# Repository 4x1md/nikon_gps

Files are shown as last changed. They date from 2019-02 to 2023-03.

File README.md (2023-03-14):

# DIY GPS Module for Nikon DSLR

The Nikon GPS project is a compact and lightweight DIY module which adds GPS functionality to Nikon DSLR cameras. It adds the ability to record location data for each photo in the EXIF and later view it on a map.

The module is attached to the flash hot shoe mount and connects to the camera's dedicated GPS port. The GPS gets its power from the camera and transmits the received GPS NMEA sentences using UART at 4800 bps. It also features an on/off button and a LED indicator which shows when the GPS module is active.

The project was created mostly to advance my DIY and electronics skills.

## Overview

The idea of building a GPS for my Nikon DSLR me after building the [GPS module for my Yaesu VX-8DE transceiver](https://github.com/4x1md/vx8_gps). I searched the internet and found some projects, some of which had a very small size. For my project I chose RG1411 GPS module which is only 10x10mm in size. It requires 3.3V which can be supplied by the camera.

The first version of the GPS had a linear voltage regulator powering the GPS module. This solution had one big disadvantage: the GPS module was turned off completely and didn't keep any GPS data while it was off. Each time the module was turned on it had to acquire all the required GPS data again and consumed more current during the first minutes after power on. The delay of 3-5 minutes and even more made this GPS module impractical while walking in a city when I turned it on and off very often in order to save camera's battery.

The second version of this GPS project had the following changes:

1. The linear voltage regulator was replaced with a switching power supply with a very high efficiency at low currents.

2. On/off button puts the GPS module is a sleep mode instead of turning it off. In this mode it keeps the GPS data all the time when the GPS is connected to the camera and its start time is much shorter than during a full power-on cycle.

This document describes the latest version of this project. The first version of this project (revision A) is presented in [revision-a.md](docs/revision-a.md).

## Circuit Diagram

The project has the following circuits: GPS module, power supply, on/off switch, logic level shifter and LEDs. All the circuits are assembled on the same PCB.

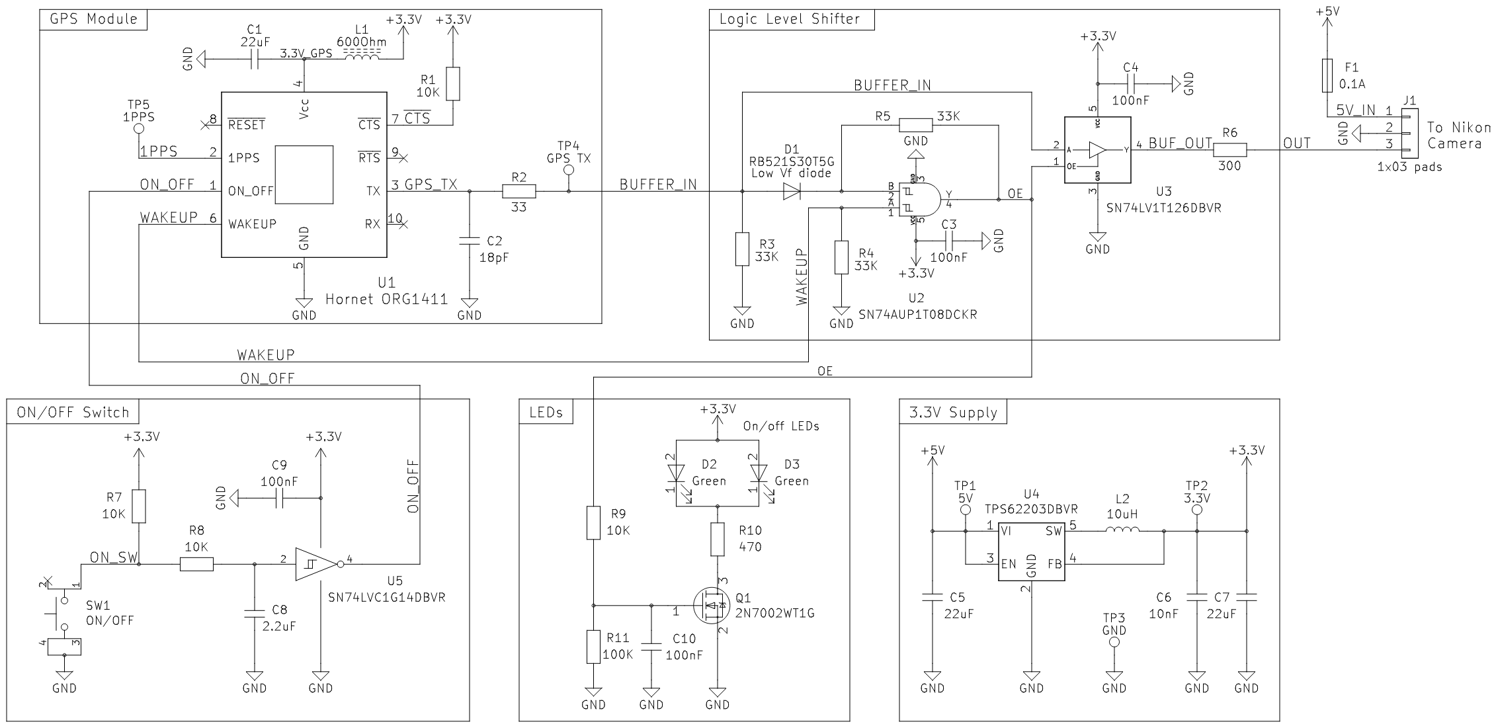
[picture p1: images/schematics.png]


1. **GPS module.** Hornet ORG1411 was chosen due to its small footprint and good performance. It is powered from the 3.3V supply and is connected in UART mode.

2. **Power supply.** TI TPS62203DBVR is a switching voltage regulator with fixed 3.3V output. It requires only an inductor and filter capacitors in order to work. It features more than 90% at the currents below 1mA. Such efficiency is important for reducing power consumption from the camera.

3. **On/off button.** The button is used to toggle the ON_OFF pin of the GPS for putting it into sleep mode or waking it up. The button is debounced by an RC-filter with a Schmitt trigger.

4. **Logic level shifter.** The logic level shifting circuit converts the 1.8V logic levels of the GPS to 3.3V levels required by the camera. When the GPS is in the sleep mode the level shifter enters high-Z mode. The enable pin of U3 is controlled by a circuit which acts like a flip-flop. If the WAKEUP pin of the GPS is LOW, the output of the AND gate U2 is also LOW and the output of U3 is disabled. After the GPS wakes up, its WAKEUP pin becomes HIGH, but the second input of U2 is still LOW, and its output continues LOW. When the UART TX of the GPS wakes up and becomes HIGH it toggles the output of U2 to HIGH. R5 pulls the B input of the AND gate up and the diode D1 prevents level of the B input from being changed to LOW by the UART RX when the latter transmits zero bits. The output of U2 will remain HIGH until the WAKEUP line falls to LOW again.

6. **LEDs.** The LEDs indicate that the GPS in in active state. They are controlled by the output of U2 and are turned off when the output buffer is in high-Z mode.

## Mechanics

The project is enclosed in a plastic box of 36x36x15mm. These boxes are cheap and are widely available on eBay/AliExpress.

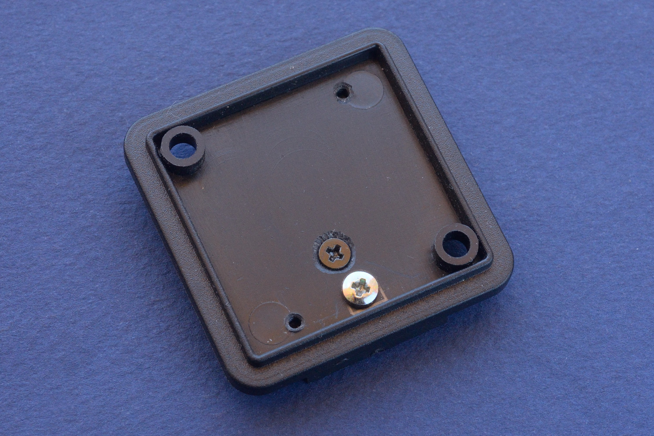
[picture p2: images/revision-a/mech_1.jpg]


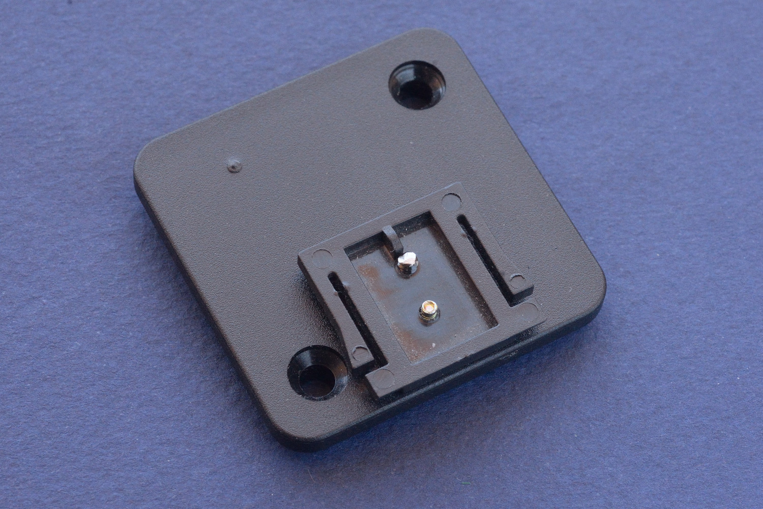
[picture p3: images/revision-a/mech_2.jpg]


## PCB Design

The PCB was designed in KiCAD. Its shape fits the plastic box shown above.

### 3D Model

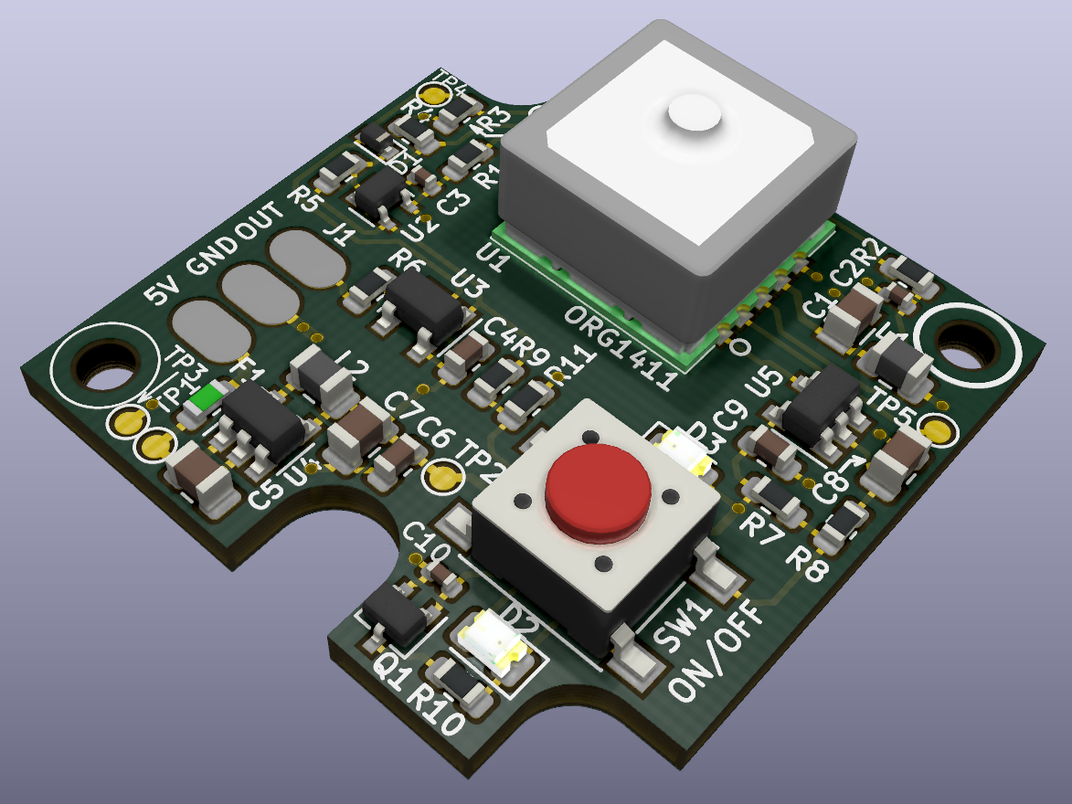
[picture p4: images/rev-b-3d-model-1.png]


PCB

### Manufactured PCB

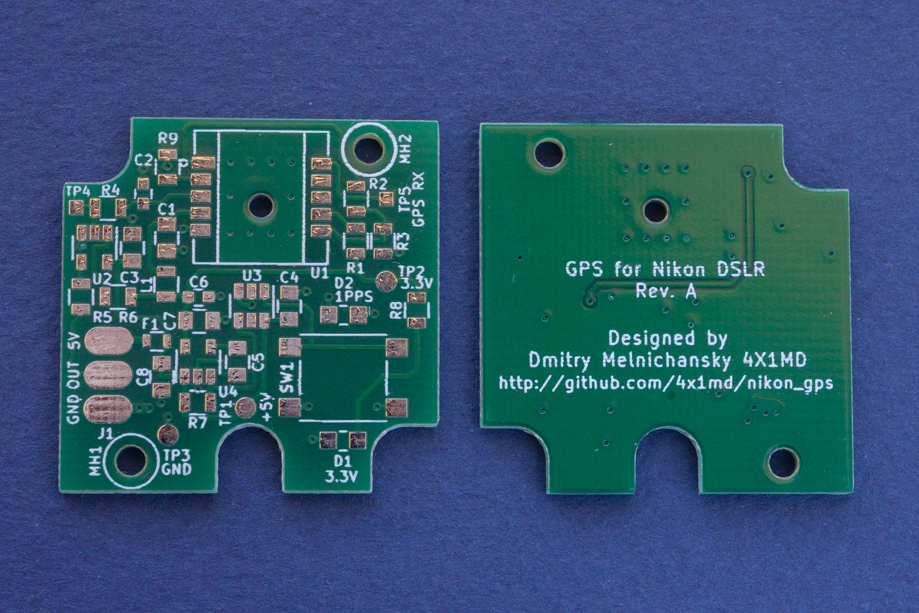
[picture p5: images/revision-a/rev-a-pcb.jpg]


## Assembled Device

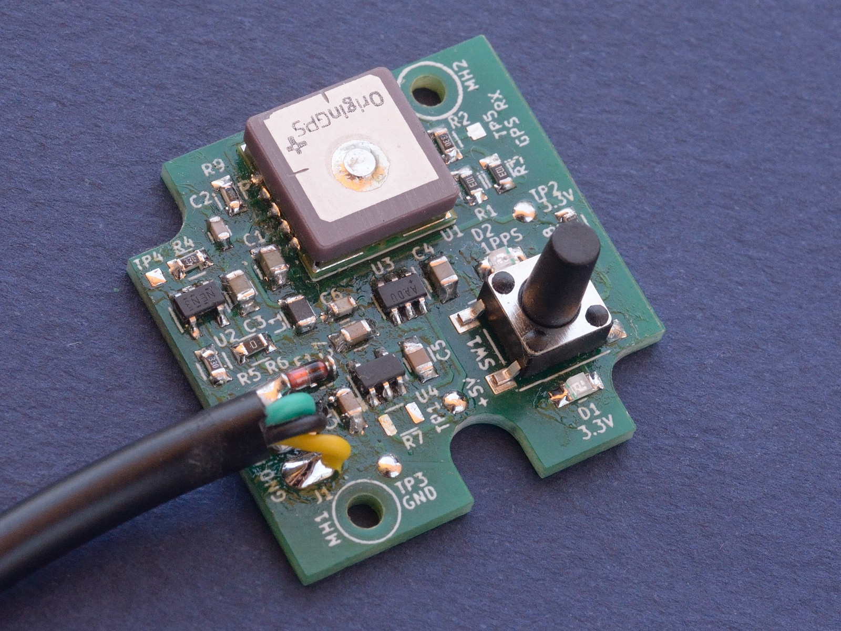
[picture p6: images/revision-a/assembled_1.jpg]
Assembled


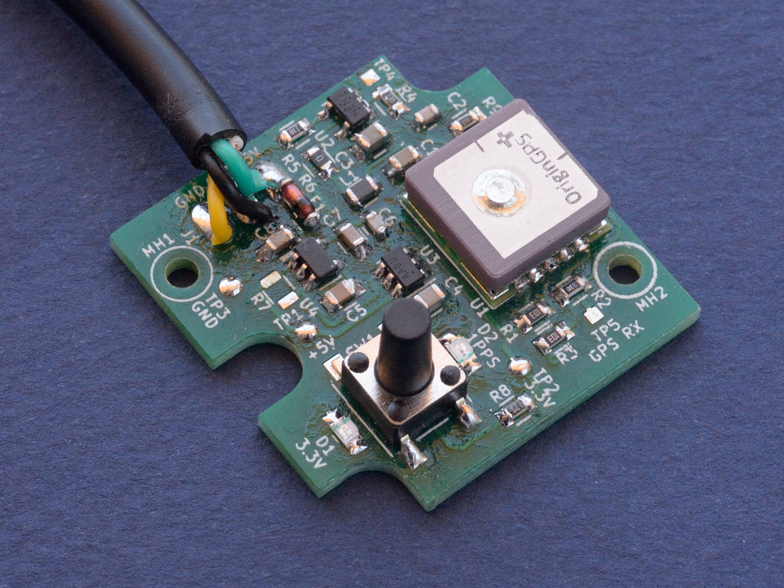
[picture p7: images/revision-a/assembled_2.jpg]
Assembled


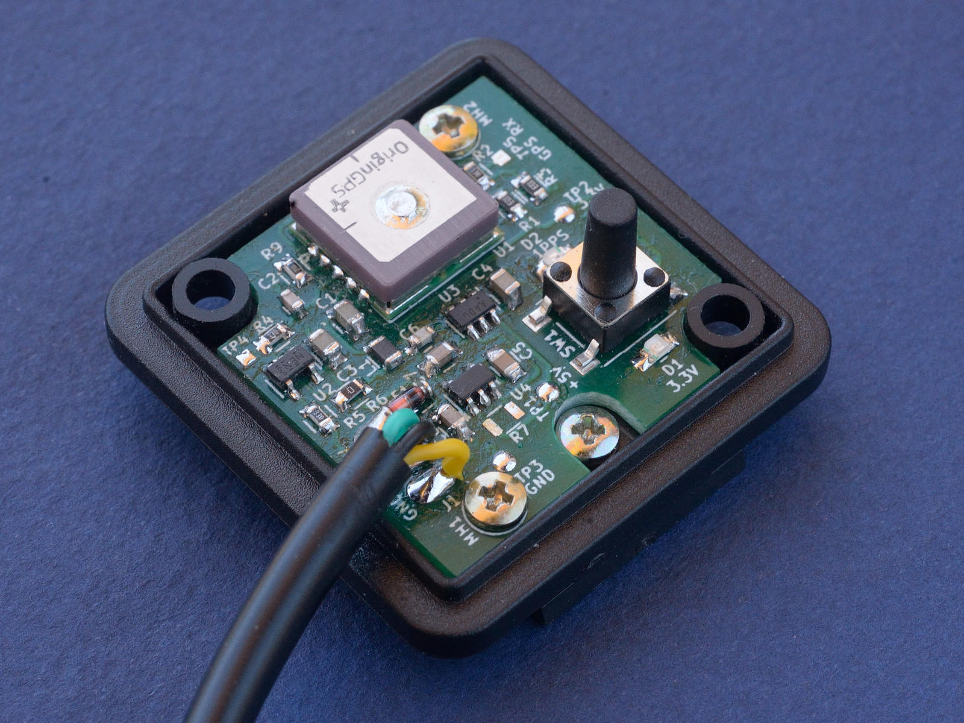
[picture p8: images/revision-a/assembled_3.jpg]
Assembled


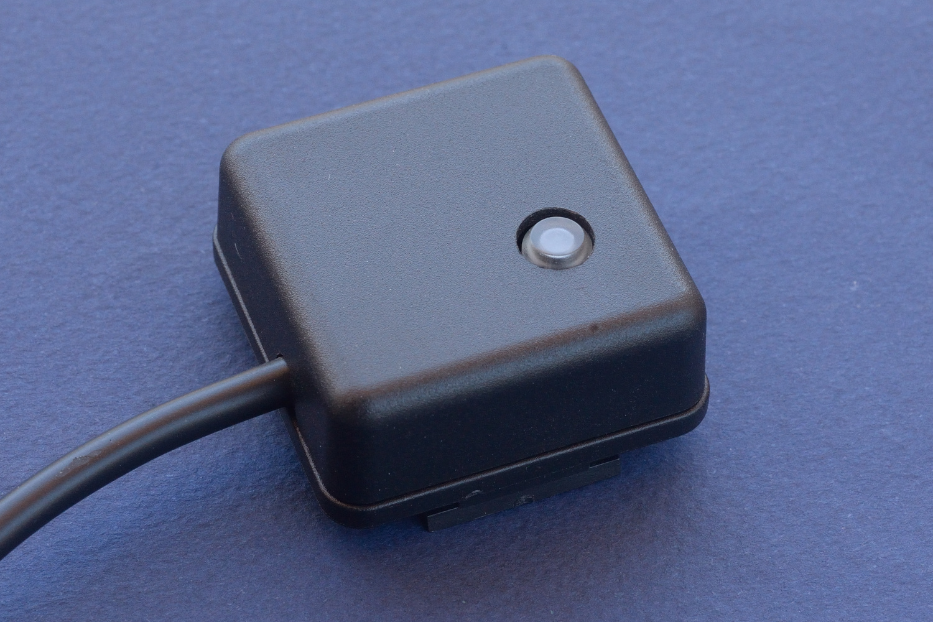
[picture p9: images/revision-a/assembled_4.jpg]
Assembled


## Device Tests

### Design Validation Tests

The tests were done in order to verify the assembled circuit. Refer to [development-tests-rev-b.md](docs/development-tests-rev-b.md) for test notes.

### ORG1411 GPS Module On/Off Tests

The on/off sequence of the ORG1411 GPS module was tested in order to understand how to connect an external on/off button to the module. Refer to [gps-on-off-tests.md](docs/gps-on-off-tests.md) for details.

### Field Tests

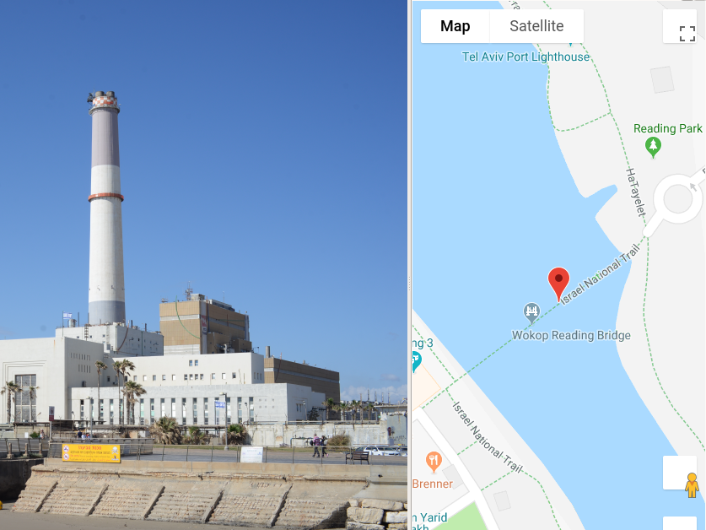
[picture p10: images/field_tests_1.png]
Field tests


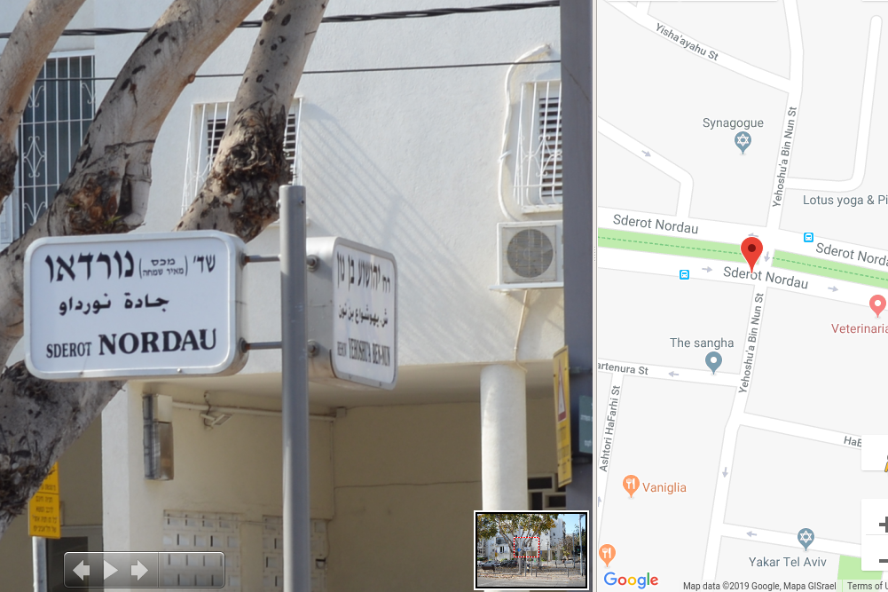
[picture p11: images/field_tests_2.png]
Field tests


## Conclusions

The second version of the module works as I expected. I tested it in Tel Aviv, Budapest and Thessaloniki and it showed fast data acquisition and good precision. Currently, I'm not planning to develop it further.

## Links

### Reference projects

1. [A low-cost GPS module for Nikon DSLRs](https://github.com/marmat/nikon-gp1-diy) by Martin Matysiak
2. [Build Notes for DIY Nikon GPS](http://www.petermillerphoto.com/nikongps/nikongps2.html) by Peter Miller

### Technical data

1. [Nikon D90, D3100, D3200, D5000, D7000 focus / shutter MC-DC2 connector pinout](http://pinoutguide.com/DigitalCameras/nikon_d90_pinout.shtml)

## Questions? Suggestions?
You are more than welcome to contact me with any questions, suggestions or propositions regarding this project. You can:

1. Visit [my QRZ.COM page](https://www.qrz.com/db/4X5DM)
2. Visit [my Facebook profile](https://www.facebook.com/Dima.Meln)
3. Write me an email to iosaaris =at= gmail dot com

## How to Support or Say Thanks

If you like this project, or found here some useful information and want to say thanks, or encourage me to do more, you can buy me a coffee!



"Buy Me A Coffee" (https://www.buymeacoffee.com/4x1md)

You can aslo make a donation with PayPal:



---

**73 de 4X1MD**

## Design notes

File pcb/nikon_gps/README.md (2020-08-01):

# nikon_gps

This directory stores the latest version of the project. Currently, revision B of the PCB developped in KiCAD 5.1.

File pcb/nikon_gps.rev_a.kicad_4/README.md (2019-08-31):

# nikon_gps.rev_a.kicad4

This directory stores the last version of the revision A of the PCB developed in KiCAD 4.x. This version was used to produce the first PCB prototypes.

The latest version is stored in [nikon_gps](../../../../pcb/nikon_gps) directory.

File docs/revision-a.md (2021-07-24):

# Revision A of DIY GPS Module for Nikon DSLR

This document shows the first version of the project.

## Overview

The first version of the GPS had an LDO for providing the supply voltage to the GPS module. The GPS was turned off by disabling the LDO and turning off the supply voltage of the GPS module. This solution has one big disadvantage: the GPS module is turned off completely and doesn't keep any GPS data while off. Each time the module is turned on it acquires all the required GPS data consumes more current during the first minutes after power on. The delay of 3-5 minutes and even more makes this GPS module impractical while walking in a city when you turn the GPS on and off very often.

## Schematics

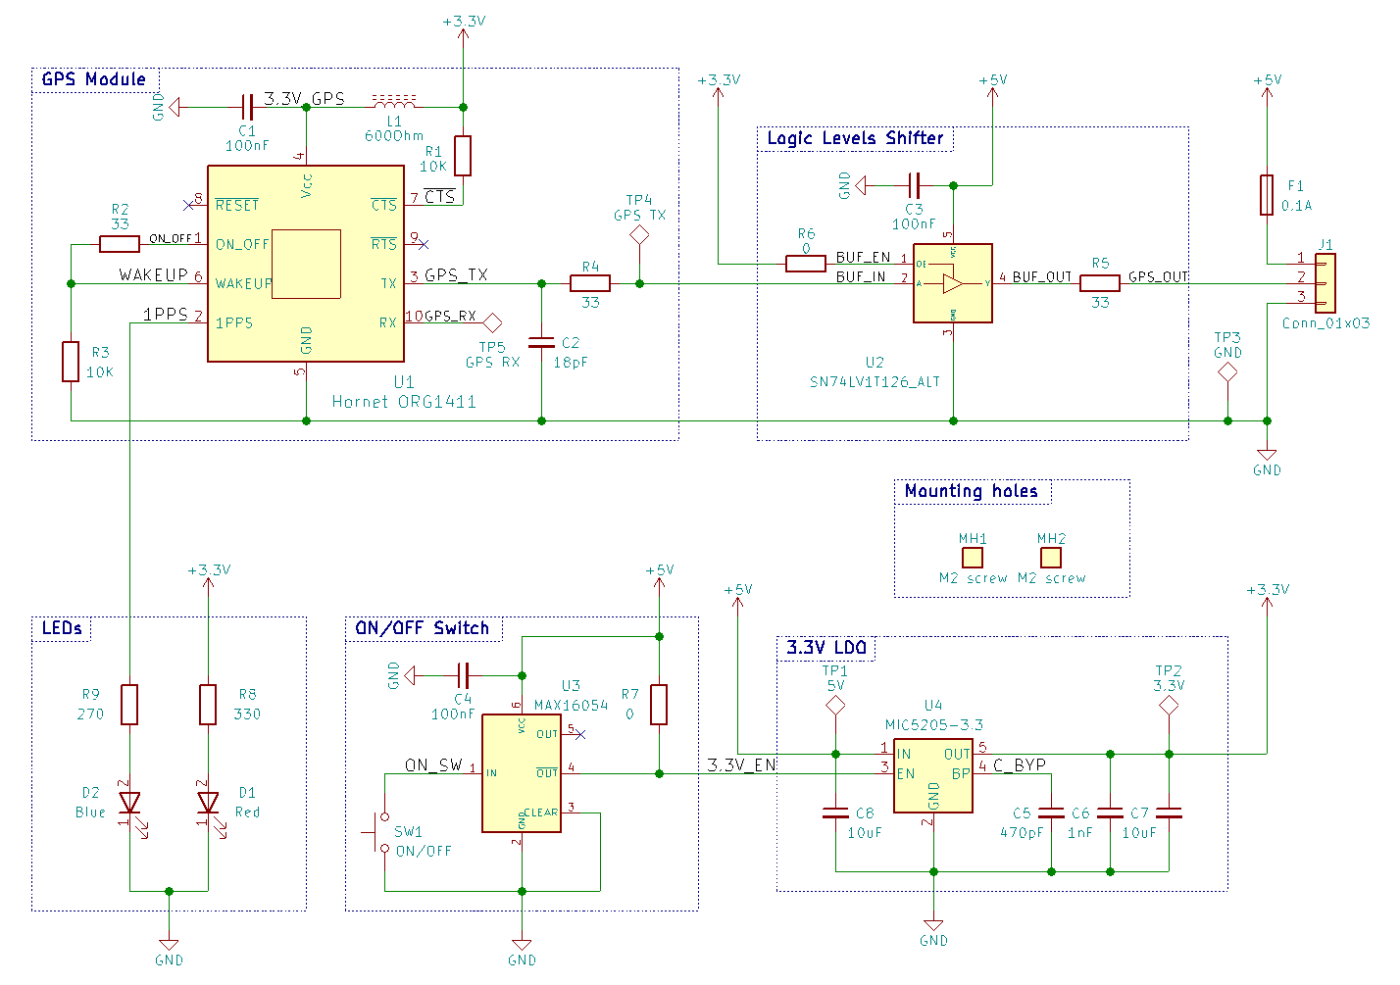
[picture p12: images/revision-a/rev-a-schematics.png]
Schematics


## Mechanics

Mechanics

Mechanics

## PCB Design

The PCB was designed in KiCAD.

### 3D Model

PCB

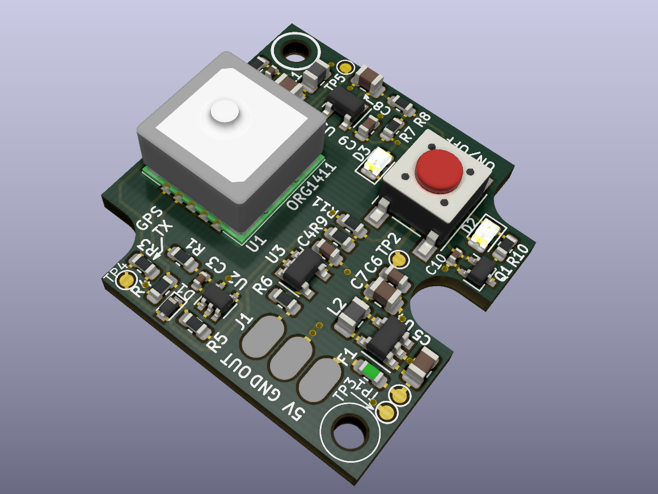
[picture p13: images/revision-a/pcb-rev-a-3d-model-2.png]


### Manufactured PCB

PCB

## Assembled Device

Assembled

Assembled

Assembled

Assembled

## Tests

The tests were done in order to verify the assembled circuit. Refer to [development-tests-rev-a.md](development-tests-rev-a.md) for test notes.

Go to [the main project page](../README.md)...

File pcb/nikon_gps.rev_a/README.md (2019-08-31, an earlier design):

# nikon_gps.rev_a

This directory stores the revision A of the PCB converted to KiCAD 5.1.

This version was not used to produce PCBs.

The latest version is stored in [nikon_gps](../../../../pcb/nikon_gps) directory.

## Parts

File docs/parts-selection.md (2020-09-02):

# Parts choice for DIY GPS for Nikon DSLR
Parts which I considered while working on this project.

## GPS modules:

1. Maestro A2235-H

	Symbol and footprint: https://www.snapeda.com/parts/A2235-H/Maestro%20Wireless/view-part/

2. Hornet ORG1411-PM04

	Datasheet: https://origingps.com/products/hornet-org1411/

	Where to buy: https://vuec.co.uk/SEMICONDUCTORS/COMMUNICATION_MODULES/GSM_GPS_GPRS_HSPA_EDGE_LTE_MODULES/ORG1411_PM04_Module_GPS_I2C_SPI_UART_40_85_C_10x10x3_8mm_SMD_2_5_5V_1130_0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

	3D model: https://grabcad.com/library/origin-gps-org1510-1

3. ORG1410-PM04

	Datasheet: https://origingps.com/products/hornet-org1410/

4. MT3339:

	https://www.instructables.com/id/Change-Baudrate-of-MT3339-PA6C-With-Arduino/

	https://www.pololu.com/product/2138/resources

## Level converters:

1. TI SN74LV1T126DBVR (Level converter, tri-state output, Output Enable)
2. Nexperia 74LV1T126GWH (Level converter, tri-state output, Output Enable, SC-70-5)
3. Nexperia 74LV1T126GVH (Level converter, tri-state output, Output Enable, SOT-23-5)
4. TI SN74LV1T34DBV (Level converter, no Output Enable pin)
5. SN74LVC1T45
6. MAX3370
7. MAX3371

## AND gates with voltage level translation

1. Nexperia
* 74LV1T08
* 74AUP1T08

2. TI
* SN74LV1T08
* SN74AUP1T08

3. ON SEMI
* MC74VHC1GT08

AUP series have Schmitt trigger inputs.

## Schmitt triggers for ON/OFF button debouncing

1. Texas Instruments SN74LVC1G14DBVR
2. Nexperia 74LVC1G14GW,125
3. Diodes Incorporated 74LVC1G14SE-7

## Diode

Low Vf Schottky diode is requred.

SOD-523

1. ON Semiconductor NSR0340V2T1G
2. ST BAS40-02V-V-G SOD-523
3. ON Semiconductor RB521S30T5G - selected diode

SOD-323

1. ON Semiconductor NSR0170HT1G SOD-323
2. ON Semiconductor NSR0240HT1G SOD-323
3. Toshiba CUS521,H3F SOD-323 - lowest Vf

## ON/OFF switch driver

1. MAX16054
https://datasheets.maximintegrated.com/en/ds/MAX16054.pdf
https://www.mouser.co.il/ProductDetail/MAX16054AZT%2bT

2. LTC2951-1/LTC2951-2
http://www.analog.com/media/en/technical-documentation/data-sheets/295112fb.pdf

3. 6x6x11mm or 6x6x12mm button.

https://www.aliexpress.com/item//32859870553.html

4. LTC6994-2

## Cable from GPS to camera

1. https://www.ebay.com/itm/Micnova-GPS-N-7-Camera-GPS-cable-for-Nikon-D3300-D3200-D5300-D7100-D7000-D610/271632524840

## Power supply

1. Analog Devices ADP2108AUJZ-3.3-R7 - buck converter, high efficiency on low currents, SOT-23-5
2. TI TPS62203DBVR - SOT-23-5
3. TPS62840 - VSON-8 - more difficult to solder

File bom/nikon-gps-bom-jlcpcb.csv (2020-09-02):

2020-09-02
Item # | Designator | Qty | Manufacturer | Mfg Part # | Description / Value | Footprint | LCSC Part Number | Type
1 | U2 | 1 | Texas Instruments | SN74LV1T08DCKR | Level translator gate,1.8/2.5/3.3 Vin,3.3V CMOS Out | SC-70-5 | C130199 | SMD
2 | U3 | 1 | Nexperia | 74HC1G126GV,125 | Voltage level translator with output enable | SOT-23-5 | C92637 | SMD
3 | U4 | 1 | Texas Instruments | TPS62203DBVR | 3.3V Out Hi-Eff Step-Down Converter | SOT-23-5 |  | SMD
4 | U5 | 1 | Texas Instruments | SN74LVC1G14DBVR | Single Schmitt-trigger inverter | SOT-23-5 | C7835 | SMD
5 | L1 | 1 | Sunlord | GZ2012D601TF | Ferrite Bead 600ohms 500mA 300mOhms 0805 | 805 | C1017 | SMD
6 | L2 | 1 | Tayio Yuden | CB2012T100KR | Inductor 0805 10uH 650mOhms +/-10% 200mA | 805 |  | SMD
7 | R1 | 1 | Uniroyal Elec | 0603WAF1002T5E | RES 10K 1%/5% 0603 | 603 | C25804 | SMD
8 | R2,R6 | 2 | Uniroyal Elec | 0603WAF330JT5E | RES 33 Ohm 1%/5% 0603 | 603 | C23140 | SMD
9 | R3,R4,R5,R7,R11 | 5 | Uniroyal Elec | 0603WAF3302T5E | RES 33 kOhm 1%/5% 0603 | 603 | C4216 | SMD
10 | R8,R9 | 2 | Uniroyal Elec | 0603WAF1001T5E | RES 1 kOhm 1%/5% 0603 | 603 | C21190 | SMD
11 | R10 | 1 | Uniroyal Elec | 0603WAF4700T5E | RES 470 Ohm 1%/5% 0603 | 603 | C23179 | SMD
12 | C1 | 1 | Samsung | CL21B105KBFNNNE | CAP 1u 10% 0805 50V | 805 | C28323 | SMD
13 | C2 | 1 | Samsung | CL05C220JB5NNNC | CAP 22p 10% 0402 | 402 | C70464 | SMD
14 | C3,C10 | 2 | Samsung | CL05B104KO5NNNC | CAP 100n 10% 0402 | 402 | C1525 | SMD
15 | C4, C9 | 2 | Samsung | CL10B104JB8NNNC | CAP 100n 10% 0603 | 603 | C24452 | SMD
16 | C5 | 1 | Samsung | CL21A475KAQNNNE | CAP 4.7u 10% 0805 | 805 | C1779 | SMD
17 | C6 | 1 | Samsung | CL10B103JB8NNNC | CAP 10n 10% 0603 | 603 | C7248 | SMD
18 | C7 | 1 | Samsung | CL10A106KP8NNNC | CAP 10u 10% 0805 | 805 | C19702 | SMD
19 | C8 | 1 | Guangdong Fenghua | 0805F225M500NT | CAP 2.2u 10% 0805 | 805 | C49217 | SMD
20 | Q1 | 1 | Leshan Radio | L2N7002WT1G | Small signal MOSFET 310mA 1.6 Ohm | SC-70-3 | C12778 | SMD
21 | D1 | 1 | Nexperia | PMEG4002EB,115 | Shottky diode | SOD-523 | C50676 | SMD
22 | D2,D3 | 2 | Everlight Elec | 17-21/GHC-YR1S2/3T | Green SMD LED | 805 | C73546 | SMD

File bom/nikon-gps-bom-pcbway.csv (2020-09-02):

2020-08-29
Item # | *Designator | *Qty | Manufacturer | *Mfg Part # | Description / Value | *Package/Footprint | Type | Your Instructions / Notes
1 | U1 | 1 | Hornet | ORG1411-PM04 |  |  | DNS
2 | U2 | 1 | Texas Instruments | SN74AUP1T08DCKR | Level translator gate,1.8/2.5/3.3 Vin,3.3V CMOS Out | SC-70-5 | SMD
3 | U3 | 1 | Texas Instruments | SN74LV1T126DBVR | Voltage level translator with output enable | SOT-23-5 | SMD
4 | U4 | 1 | Texas Instruments | TPS62203DBVR | 3.3V Out Hi-Eff Step-Down Converter | SOT-23-5 | SMD
5 | U5 | 1 | Texas Instruments | SN74LVC1G14DBVR | Single Schmitt-trigger inverter | SOT-23-5 | SMD
6 | L1 | 1 | TDK | MPZ2012S601AT000 | Ferrite Bead 600ohms 2A 100mOhms 0805 | 805 | SMD
7 | L2 | 1 | Tayio Yuden | CB2012T100KR | Inductor 0805 10uH 650mOhms +/-10% 200mA | 805 | SMD
8 | R1 | 1 | Yageo | RC0603FR-0710KL | RES 10K 1%/5% 0603 | 603 | SMD
9 | R2,R6 | 2 | Yageo | RC0603FR-0733RL | RES 33 Ohm 1%/5% 0603 | 603 | SMD
10 | R3,R4,R5,R7,R11 | 5 | Yageo | AC0603FR-1033KL | RES 33 kOhm 1%/5% 0603 | 603 | SMD
11 | R8,R9 | 2 | Yageo | RC0603FR-071KL | RES 1 kOhm 1%/5% 0603 | 603 | SMD
12 | R10 | 1 | Yageo | AC0603FR-10470RL | RES 470 Ohm 1%/5% 0603 | 603 | SMD
13 | C1 | 1 | Kemet | C0805C105K3RACTU | CAP 1u 10% 0805 | 805 | SMD
14 | C2 | 1 | Yageo | AC0402JRNPO9BN180 | CAP 18p 10% 0402 | 402 | SMD
15 | C3,C10 | 2 | Tayio Yuden | TMK105B7104MV-FR | CAP 100n 10% 0402 | 402 | SMD
16 | C4, C9 | 2 | Kemet | C0603C104M4RACAUTO | CAP 100n 10% 0603 | 603 | SMD
17 | C5 | 1 | Walsin | 0805X475M250CT | CAP 4.7u 10% 0805 | 805 | SMD
18 | C6 | 1 | Kemet | C0603C104M4RACAUTO | CAP 10n 10% 0603 | 603 | SMD
19 | C7 | 1 | Walsin | 0805F106Z6R3CT | CAP 10u 10% 0805 | 805 | SMD
20 | C8 | 1 | Walsin | 0805X225M160CT | CAP 2.2u 10% 0805 | 805 | SMD
21 | Q1 | 1 | ON Semiconductor | 2N7002WT1G | Small signal MOSFET 310mA 1.6 Ohm | SC-70-3 | SMD
22 | D1 | 1 | ON Semiconductor | RB521S30T5G | Shottky diode | SOD-523 | SMD
23 | D2,D3 | 2 | Wurth Elektronik | 150080VS75000 | Green SMD LED | 805 | SMD
24 | SW1 | 0 |  |  |  |  | DNS

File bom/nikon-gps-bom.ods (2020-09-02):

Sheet: PCBWay
DIY Nikon GPS BOM |  |  |  | 2020-08-07
 |  |  |  |  |  |  |  |  |  |  | Alternate parts
Item # | *Designator | *Qty | Manufacturer | *Mfg Part # | Description / Value | *Package/Footprint | Type | Price | Total price | Your Instructions / Notes | Manufacturer | *Mfg Part # | Price | Total price
1 | U1 | 1 | Hornet | ORG1411-PM04 |  |  | DNS
2 | U2 | 1 | Texas Instruments | SN74AUP1T08DCKR | Level translator gate,1.8/2.5/3.3 Vin,3.3V CMOS Out | SC-70-5 | SMD | 0.35 | 0.35 | Alternative: Nexperia 74AUP1T08GWH | Nexperia | 74AUP1T08GWH | 0.43 | 0.43
3 | U3 | 1 | Texas Instruments | SN74LV1T126DBVR | Voltage level translator with output enable | SOT-23-5 | SMD | 0.46 | 0.46 | Alternative: Nexperia 74LV1T126GVH | Texas Instruments | SN74LV1T126DBVR | 0.46 | 0.46
4 | U4 | 1 | Texas Instruments | TPS62203DBVR | 3.3V Out Hi-Eff Step-Down Converter | SOT-23-5 | SMD | 1.19 | 1.19 |  | Analog Devices | ADP2108AUJZ-3.3-R7 | 1.83 | 1.83
5 | U5 | 1 | Texas Instruments | SN74LVC1G14DBVR | Single Schmitt-trigger inverter | SOT-23-5 | SMD | 0.29 | 0.29 | Alternatives: Diodes Inc 74LVC1G14SE-7, Nexperia 74LVC1G14GV,125 | Nexperia | 74LVC1G14GV,125 | 0.3 | 0.3
6 | L1 | 1 | TDK | MPZ2012S601AT000 | Ferrite Bead 600ohms 2A 100mOhms 0805 | 805 | SMD | 0.11 | 0.11 |  | TDK | MPZ2012S601AT000 | 0.11 | 0.11
7 | L2 | 1 | Tayio Yuden | CB2012T100KR | Inductor 0805 10uH 650mOhms +/-10% 200mA | 0805 | SMD | 0.23 | 0.23 |  | TDK | MLP2016S1R0MT0S1 | 0.36 | 0.36
8 | R1 | 1 | Yageo | RC0603FR-0710KL | RES 10K 1%/5% 0603 | 0603 | SMD | 0.1 | 0.1 |  | Yageo | RC0603FR-0710KL | 0.1 | 0.1
9 | R2,R6 | 2 | Yageo | RC0603FR-0733RL | RES 33 Ohm 1%/5% 0603 | 0603 | SMD | 0.1 | 0.2 |  | Yageo | RC0603FR-0733RL | 0.1 | 0.2
10 | R3,R4,R5,R7,R11 | 5 | Yageo | AC0603FR-1033KL | RES 33 kOhm 1%/5% 0603 | 0603 | SMD | 0.1 | 0.5 |  | Yageo | AC0603FR-1033KL | 0.1 | 0.5
11 | R8,R9 | 2 | Yageo | RC0603FR-071KL | RES 1 kOhm 1%/5% 0603 | 0603 | SMD | 0.1 | 0.2 |  | Yageo | RC0603FR-071KL | 0.1 | 0.2
12 | R10 | 1 | Yageo | AC0603FR-10470RL | RES 470 Ohm 1%/5% 0603 | 0603 | SMD | 0.1 | 0.1 |  | Yageo | AC0603FR-10470RL | 0.1 | 0.1
13 | C1 | 1 | Kemet | C0805C105K3RACTU | CAP 1u 10% 0805 | 0805 | SMD | 0.14 | 0.14 |  | Kemet | C0805C105K3RACTU | 0.14 | 0.14
14 | C2 | 1 | Yageo | AC0402JRNPO9BN180 | CAP 18p 10% 0402 | 0402 | SMD | 0.1 | 0.1 |  | Yageo | AC0402JRNPO9BN180 | 0.1 | 0.1
15 | C3,C10 | 2 | Tayio Yuden | TMK105B7104MV-FR | CAP 100n 10% 0402 | 0402 | SMD | 0.1 | 0.2 |  | Tayio Yuden | TMK105B7104MV-FR | 0.1 | 0.2
16 | C4, C9 | 2 | Kemet | C0603C104M4RACAUTO | CAP 100n 10% 0603 | 0603 | SMD | 0.1 | 0.2 |  | Kemet | C0603C104M4RACAUTO | 0.1 | 0.2
17 | C5 | 1 | Walsin | 0805X475M250CT | CAP 4.7u 10% 0805 | 0805 | SMD | 0.1 | 0.1 |  | Walsin | 0805X475M250CT | 0.1 | 0.1
18 | C6 | 1 | Kemet | C0603C104M4RACAUTO | CAP 10n 10% 0603 | 0603 | SMD | 0.1 | 0.1 |  | Kemet | C0603C104M4RACAUTO | 0.1 | 0.1
19 | C7 | 1 | Walsin | 0805F106Z6R3CT | CAP 10u 10% 0805 | 0805 | SMD | 0.1 | 0.1 |  | Walsin | 0805F106Z6R3CT | 0.1 | 0.1
20 | C8 | 1 | Walsin | 0805X225M160CT | CAP 2.2u 10% 0805 | 0805 | SMD | 0.1 | 0.1 |  | Walsin | 0805X225M160CT | 0.1 | 0.1
21 | Q1 | 1 | ON Semiconductor | 2N7002WT1G | Small signal MOSFET 310mA 1.6 Ohm | SC-70-3 | SMD | 0.21 | 0.21 |  | ON Semiconductor | 2N7002WT1G | 0.21 | 0.21
22 | D1 | 1 | ON Semiconductor | RB521S30T5G | Shottky diode | SOD-523 | SMD | 0.14 | 0.14 |  | ON Semiconductor | RB521S30T5G | 0.14 | 0.14
23 | D2,D3 | 2 | Wurth Elektronik | 150080VS75000 | Green SMD LED | 0805 | SMD | 0.18 | 0.36 |  | Wurth Elektronik | 150080VS75000 | 0.18 | 0.36
24 | SW1 | 0 |  |  |  |  | DNS | 0 | 0 |  | 0 | 0 | 0 | 0
 | Sum: | 32 |  |  |  |  |  | Sum: | 5.48 |  |  |  | Sum: | 6.34

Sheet: JLCPCB
DIY Nikon GPS BOM |  |  |  | 2020-08-07
Item # | Designator | Qty | Manufacturer | Mfg Part # | Description / Value | Footprint | LCSC Part Number | Type | Price | Total price | Instructions / Notes
1 | U1 | 0 | Hornet | ORG1411-PM04 |  |  |  | DNS |  | 0
2 | U2 | 1 | Texas Instruments | SN74LV1T08DCKR | Level translator gate,1.8/2.5/3.3 Vin,3.3V CMOS Out | SC-70-5 | C130199 | SMD | 0.172 | 0.172
3 | U3 | 1 | Nexperia | 74HC1G126GW,125 | Voltage level translator with output enable | SOT-23-5 |  | SMD |  | 0
4 | U4 | 1 | Texas Instruments | TPS62203DBVR | 3.3V Out Hi-Eff Step-Down Converter | SOT-23-5 | C9051 | SMD | 1.867 | 1.8667
5 | U5 | 1 | Texas Instruments | SN74LVC1G14DBVR | Single Schmitt-trigger inverter | SOT-23-5 | C7835 | SMD | 0.070 | 0.0701
6 | L1 | 1 | Sunlord | GZ2012D601TF | Ferrite Bead 600ohms 500mA 300mOhms 0805 | 0805 | C1017 | SMD | 0.012 | 0.0116
7 | L2 | 1 | Tayio Yuden | CB2012T100KR | Inductor 0805 10uH 650mOhms +/-10% 200mA | 0805 |  | SMD |  | 0
8 | R1 | 1 | Uniroyal Elec | 0603WAF1002T5E | RES 10K 1%/5% 0603 | 0603 | C25804 | SMD | 0.002 | 0.0018
9 | R2,R6 | 2 | Uniroyal Elec | 0603WAF330JT5E | RES 33 Ohm 1%/5% 0603 | 0603 | C23140 | SMD | 0.002 | 0.0042
10 | R3,R4,R5,R7,R11 | 5 | Uniroyal Elec | 0603WAF3302T5E | RES 33 kOhm 1%/5% 0603 | 0603 | C4216 | SMD | 0.002 | 0.0105
11 | R8,R9 | 2 | Uniroyal Elec | 0603WAF1001T5E | RES 1 kOhm 1%/5% 0603 | 0603 | C21190 | SMD | 0.002 | 0.0042
12 | R10 | 1 | Uniroyal Elec | 0603WAF4700T5E | RES 470 Ohm 1%/5% 0603 | 0603 | C23179 | SMD | 0.002 | 0.0021
13 | C1 | 1 | Samsung | CL21B105KBFNNNE | CAP 1u 10% 0805 50V | 0805 | C28323 | SMD | 0.022 | 0.0224
14 | C2 | 1 | Samsung | CL05C220JB5NNNC | CAP 22p 10% 0402 | 0402 | C70464 | SMD | 0.003 | 0.0025
15 | C3,C10 | 2 | Samsung | CL05B104KO5NNNC | CAP 100n 10% 0402 | 0402 | C1525 | SMD | 0.004 | 0.0072
16 | C4, C9 | 2 | Samsung | CL10B104JB8NNNC | CAP 100n 10% 0603 | 0603 | C24452 | SMD | 0.016 | 0.0318
17 | C5 | 1 | Samsung | CL21A475KAQNNNE | CAP 4.7u 10% 0805 | 0805 | C1779 | SMD | 0.021 | 0.0208
18 | C6 | 1 | Samsung | CL10B103JB8NNNC | CAP 10n 10% 0603 | 0603 | C7248 | SMD | 0.009 | 0.0091
19 | C7 | 1 | Samsung | CL10A106KP8NNNC | CAP 10u 10% 0805 | 0805 | C19702 | SMD | 0.013 | 0.0129
20 | C8 | 1 | Guangdong Fenghua | 0805F225M500NT | CAP 2.2u 10% 0805 | 0805 | C49217 | SMD | 0.029 | 0.0293
21 | Q1 | 1 | Leshan Radio | L2N7002WT1G | Small signal MOSFET 310mA 1.6 Ohm | SC-70-3 | C12778 | SMD | 0.021 | 0.0205
22 | D1 | 1 | Nexperia | PMEG4002EB,115 | Shottky diode | SOD-523 | C50676 | SMD | 0.063 | 0.0628
23 | D2,D3 | 2 | Everlight Elec | 17-21/GHC-YR1S2/3T | Green SMD LED | 0805 | C73546 | SMD | 0.074 | 0.148
 | Sum: | 31 |  |  |  |  |  |  | Sum: | 2.51

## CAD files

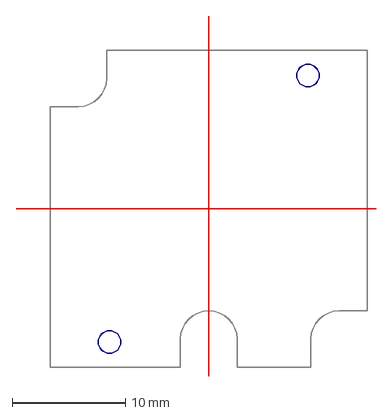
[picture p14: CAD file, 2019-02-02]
mechanics/pcb_with_dimensions.dxf
31.8 x 31.8 mm

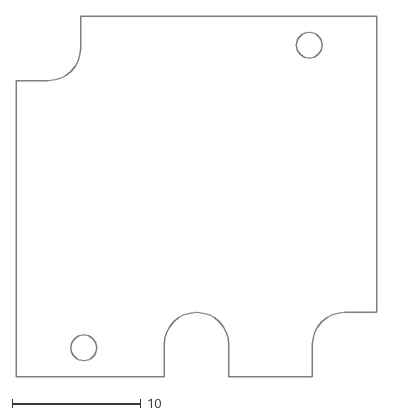
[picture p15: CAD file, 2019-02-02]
mechanics/pcb.dxf
28.0 x 28.0

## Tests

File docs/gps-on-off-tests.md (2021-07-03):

# ORG1411 GPS Module On/Off Tests

# Autonomous Power-On

Connecting WAKEUP output (pin 6) to ON_OFF input (pin 1) enables automatic GPS module start from Ready-To-Start state to Full Power state.

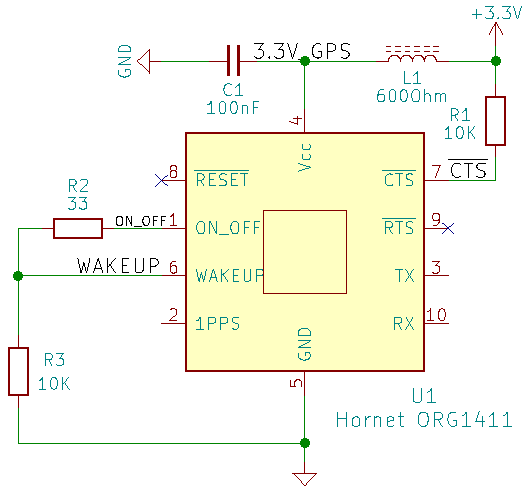
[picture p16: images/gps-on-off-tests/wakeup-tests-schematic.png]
Schematic


In the first version of Nikon GPS WAKEUP output (pin 6) is connected to ON_OFF input (pin 1) through the 30 Ohm resistor R2.

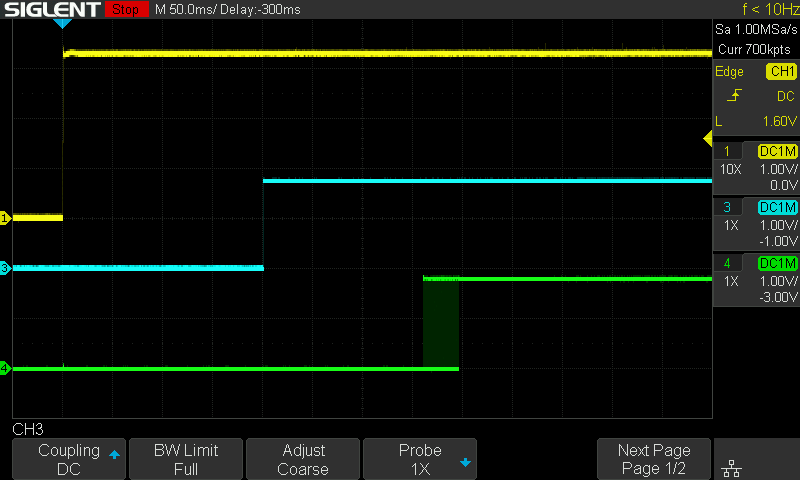
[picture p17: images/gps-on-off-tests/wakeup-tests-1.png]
Scope Image


Channel  | Signal
--- | ---
**CH1:** | 3.3V
**CH2:** | None
**CH3:** | WAKEUP (pin 6)
**CH4:** | GPS_TX (p)in 3)

# On/Off Switch Configuration

In this configuration the GPS module is turned on and off by ON_OFF signal (pin 1) which is controlled by an external on/off button.

## Wake-Up After Power-On

GPS module wake-up with ON_OFF and WAKEUP disconnected.

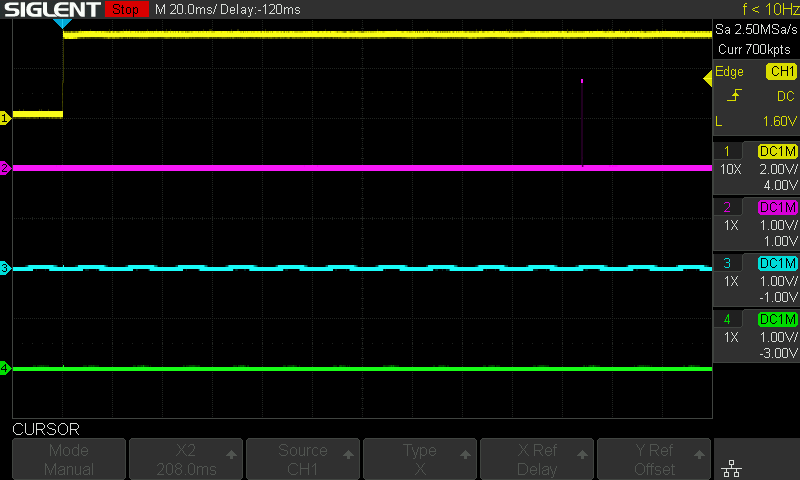
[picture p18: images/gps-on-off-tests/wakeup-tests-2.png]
Scope Image


Channel  | Signal
--- | ---
**CH1:** | 3.3V
**CH2:** | WAKEUP (pin 6)
**CH3:** | ON_OFF (pin 1)
**CH4:** | GPS_TX (pin 3)

Time from 3.3V wake-up to WAKEUP rise is 207.404ms. WAKEUP pulse length is 366us.

## On/Off Sequence

The ON_OFF pulse was generated by an external AWG.

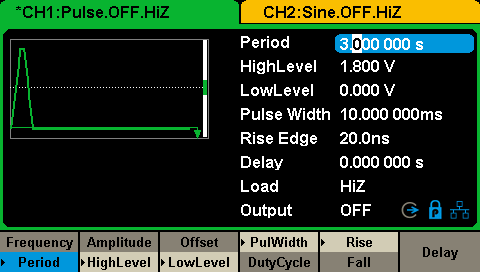
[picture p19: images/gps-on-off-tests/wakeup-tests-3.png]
Scope Image


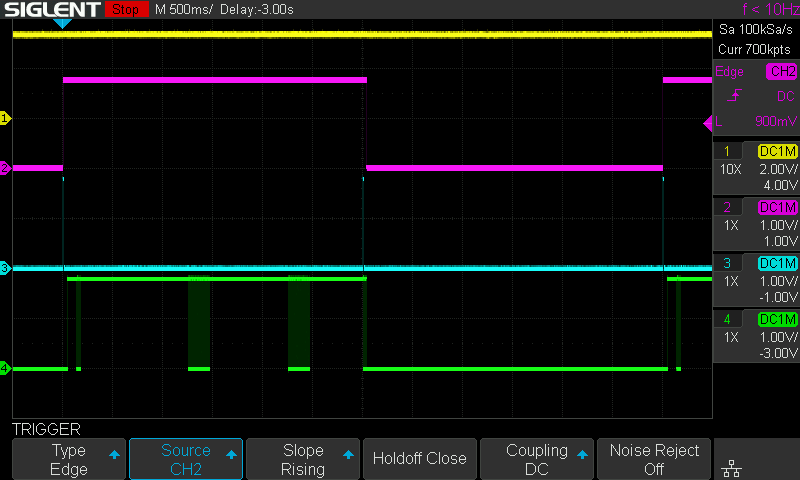
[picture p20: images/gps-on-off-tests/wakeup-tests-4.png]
Scope Image


Channel  | Signal
--- | ---
**CH1:** | 3.3V
**CH2:** | WAKEUP (pin 6)
**CH3:** | ON_OFF (pin 1)
**CH4:** | GPS_TX (pin 3)

## GPS On Sequence

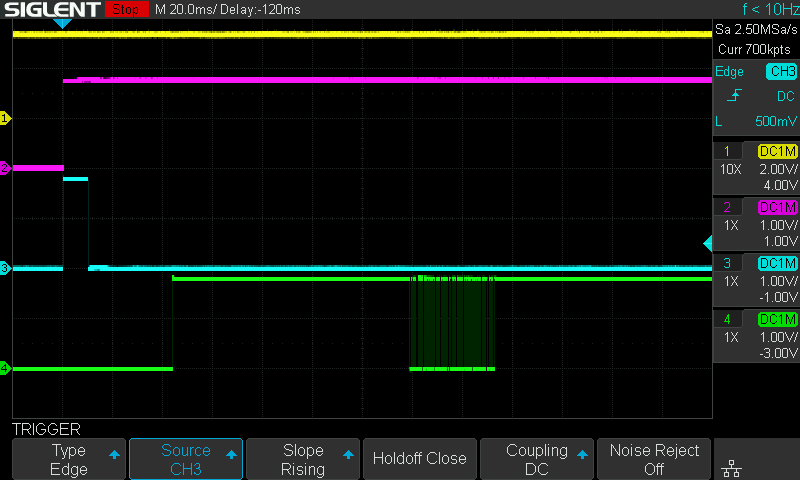
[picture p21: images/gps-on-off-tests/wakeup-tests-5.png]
Scope Image


Channel  | Signal
--- | ---
**CH1:** | 3.3V
**CH2:** | WAKEUP (pin 6)
**CH3:** | ON_OFF (pin 1)
**CH4:** | GPS_TX (pin 3)

## GPS Off Sequence

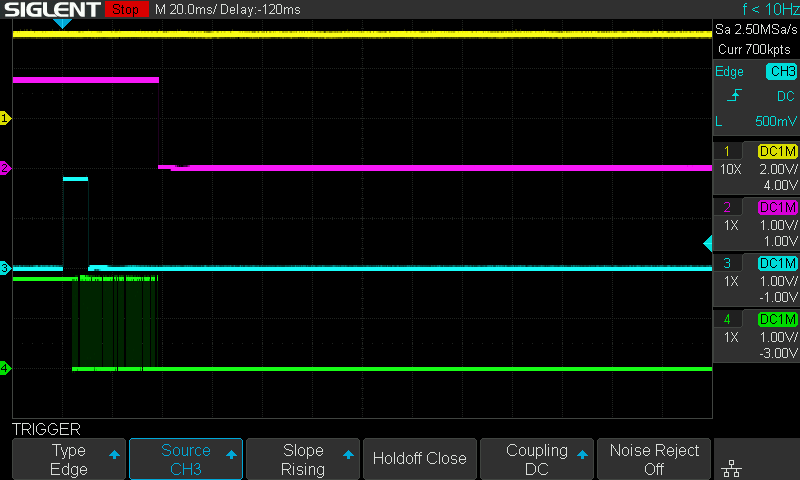
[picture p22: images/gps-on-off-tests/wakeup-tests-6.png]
Scope Image


Channel  | Signal
--- | ---
**CH1:** | 3.3V
**CH2:** | WAKEUP (pin 6)
**CH3:** | ON_OFF (pin 1)
**CH4:** | GPS_TX (pin 3)

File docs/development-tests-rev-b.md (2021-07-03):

# Design validation DIY GPS for Nikon DSLR Revision B

## Test equipment

1. Siglent SDS1204X-E oscilloscope
2. GOPHET CPS-3205 II power supply
3. UNI-T UT61E DMM
4. Siglent SDG1032X signal generator

## Tested Circuit
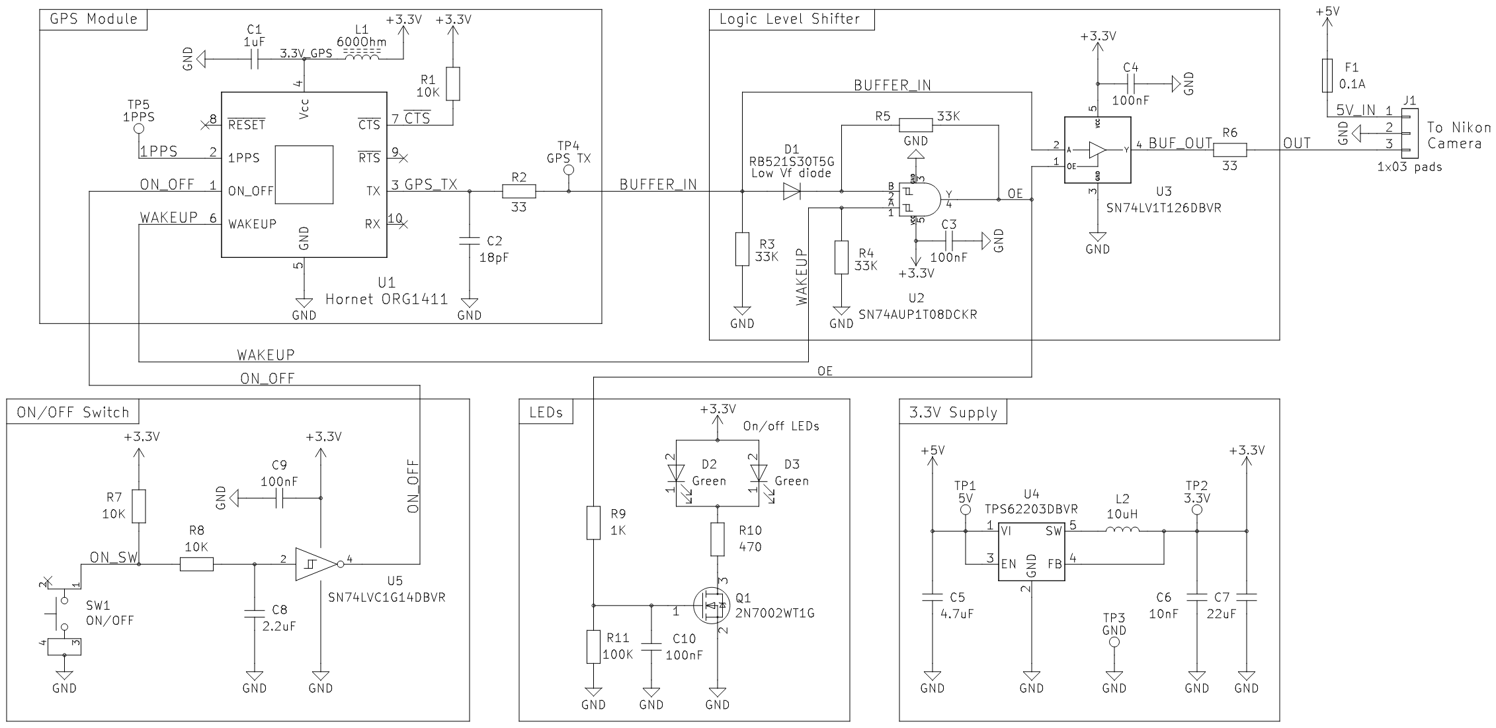
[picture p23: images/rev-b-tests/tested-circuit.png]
Schematic


## Tests without GPS module
The GPS module is hard to manually solder and especially desolder. Therefore, before assembling it, I needed to make sure that all the other circuits work as expected.

### Power supply

#### Wake-up with no load

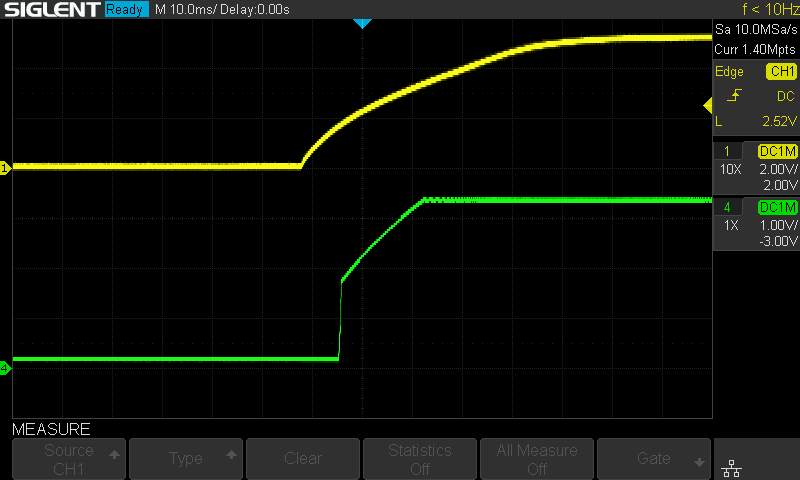
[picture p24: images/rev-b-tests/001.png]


Channel | Signal |
--- | ---
**CH1:** | 5V input (TP1)
**CH4:** | 3.3V (TP2)

#### Power-off with no load

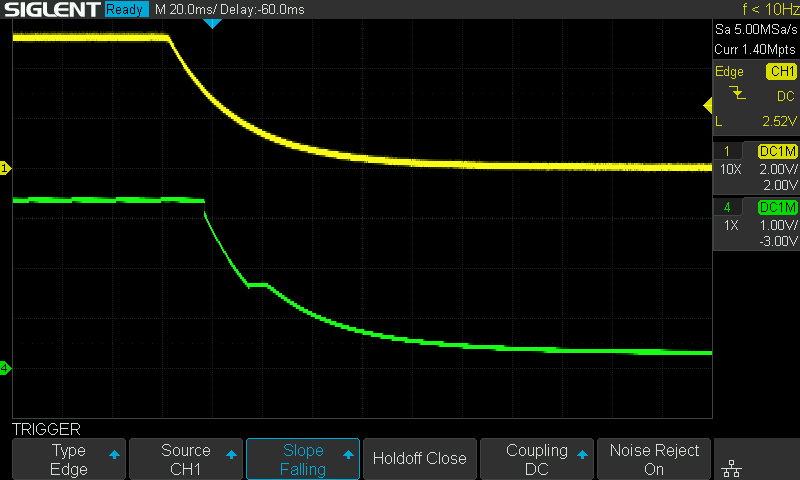
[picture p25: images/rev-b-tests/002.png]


Channel | Signal |
--- | ---
**CH1:** | 5V input (TP1)
**CH4:** | 3.3V (TP2)

#### Wake-up with load

Wake-up with load was tested with a 33 Ohm resistor (100mA load current) connected between the buck output and GND.

Wavewform

Channel | Signal |
--- | ---
**CH1:** | 5V input (TP1)
**CH4:** | 3.3V (TP2)

#### Power-off with load

Wavewform

Channel | Signal |
--- | ---
**CH1:** | 5V input (TP1)
**CH4:** | 3.3V (TP2)

#### Zoom-in on the wake-up with load

Wavewform

Channel | Signal |
--- | ---
**CH4:** | 3.3V (TP2)

Wake-up of 3.3V matches output voltage start-up shown in the datasheet:

Wavewform

#### Ripple without load

According to the datasheet, at light load currents, the device operates in power save mode and the output voltage ripple is independent of the output capacitor value. The output voltage ripple is set by the internal comparator thresholds. The typical output voltage ripple is 1% of the output voltage, therefore we'd expect ripple of 33mVpp. The measured ripple is ~27mVpp.

Wavewform

Channel | Signal |
--- | ---
**CH1:** | 3.3V (TP2)

#### Ripple with 100mA load

Wavewform

Channel | Signal |
--- | ---
**CH1:** | 3.3V (TP2)

The converter shows a very low ripple at 100mA load.

#### Ripple with 15mA load

Wavewform

Channel | Signal |
--- | ---
**CH1:** | 3.3V (TP2)

#### Ripple with 40mA load

40mA current was chosen as a typical load current of the GPS module.

Wavewform

Channel | Signal |
--- | ---
**CH1:** | 3.3V (TP2)

### Line regulation

The DC-DC converter was tested with a load of 70 Ohm consisting of a 68 Ohm resistor and 2 Ohm internal resistance of the ammeter.

Test conditions | Vin, V | Iin, mA | Vout, V | Iout, mA | Efficiency, %
--- | --- | --- | --- | --- | ---
Vin = 4.5V, RL=70 Ohm | 4.498 | 36.59 | 3.3431 | 46.60 | 94.65%
Vin = 5.0V, RL=70 Ohm | 5.004 | 34.23 | 3.3434 | 47.90 | 93.49%
Vin = 5.5V, RL=70 Ohm | 5.503 | 31.66 | 3.3426 | 48.40 | 92.86%

### Load regulation

Load regulation was tested with three load currents: 5mA, 50mA and 100mA. It was difficult to get precise currents because fixed resistors were used as loads.

Test conditions | Vin, V | Iin, mA | Vout, V | Iout, mA | Efficiency, %
--- | --- | --- | --- | --- | ---
Vin = 5.0V, RL=682 Ohm | 5.0099 | 3.59 | 3.3407 | 5.00 | 92.77%
Vin = 5.0V, RL=70 Ohm | 5.0039 | 34.58 | 3.3434 | 48.50 | 93.71%
Vin = 5.0V, RL=35 Ohm | 5.0043 | 67.09 | 3.3107 | 94.50 | 93.19%

### Dynamic Load

Dynamic load was tested with a fixed resistors, switched by a MOSFET. Switching frequency was 1kHz with duty cycle of 50%. A sense resistor of 1 Ohm was used to monitor the load current.

Dynamic load schematic

**Switching between 4.4mA and 52mA (743 Ohm and 62 Ohm)**

Wavewform

Wavewform

Wavewform

Channel | Signal |
--- | ---
**CH1:** | 3.3V (TP2)
**CH4:** | Current sense

The waveforms show ripple frequency and amplitude change when the load current changes.

**Switching between 4.6mA and 87mA (714 Ohm and 33 Ohm)**

Wavewform

Wavewform

Wavewform

Channel | Signal |
--- | ---
**CH1:** | 3.3V (TP2)
**CH4:** | Current sense

There are spikes of approx. 200mV when the load current changes from 4.6mA to almost 100mA. According to the datasheet of TPS62203, such spikes are normal for large load current changes.

Wavewform

#### Results and conclusions

At first, the output capacitor was 10uF. The ripples were 37mVpp at light loads and 76mVpp at 100mA. After changing the capacitor to 22uF, the ripples became 27.2mVpp and 18mVpp which is acceptable for this design.

Ripple at low currents (15-40mA) reaches 50mV which is relatively high, but the GPS module has a built-in LDO which is supposed to be able to deal with it.

According to the datasheet of the ORG1411 GPS, it can have inrush current of up to 100mA for about 20μs. Maximum steady-state current is 47mA during acquisition. The power supply used in this project will be able to supply these currents to the GPS module.

### On/off button

#### Wake-up

Wavewform

Channel | Signal
--- | ---
**CH2:** | Push button (SW1.1)
**CH3:** | Schmitt trigger in (U5.2)
**CH4:** | Schmitt trigger out (U5.4)

Pulse duration on the output of the Schmitt trigger is 36.4ms. Start time of the GPS module is at least 300ms. During the start period of the GPS module the state of the ON_OFF pin is ignored.

#### On/off pulse on button press

Wavewform

Channel | Signal
--- | ---
**CH2:** | Push button (SW1.1)
**CH3:** | Schmitt trigger in (U5.2)
**CH4:** | Schmitt trigger out (U5.4)

On/off pulse duration is around 254ms and depends on the time the button remains pressed. ORG1411 datasheet recommends ON_OFF pulse duration of 100ms or higher.

#### Button debouncing

Wavewform

Wavewform

Channel | Signal
--- | ---
**CH2:** | Push button (SW1.1)
**CH3:** | Schmitt trigger in (U5.2)
**CH4:** | Schmitt trigger out (U5.4)

The debouncing time of the circuit is approx. 14.8ms. Increasing R8 will increase this time.

#### Results and conclusions

Push button debouncing circuit works as expected.

### Logic level shifter and output enable

#### Wake-up

Wavewform

Channel | Signal
--- | ---
**CH1:** | 3.3V (TP2)
**CH2:** | Buffer in (TP4)
**CH3:** | OE (U3.1)
**CH4:** | Out (J1.3)

#### Power-off

Wavewform

Channel | Signal
--- | ---
**CH1:** | 3.3V (TP2)
**CH2:** | Buffer in (TP4)
**CH3:** | OE (U3.1)
**CH4:** | Out (J1.3)

#### Output enable

Output enable circuit works as a latch. After WAKEUP signal of the GPS becomes HIGH, the latch is triggered by the first UART TX LOW-HIGH transition and the AND gate output becomes HIGH. In this state, resistor R5 pulls the B input of the AND gate up independently of the UART TX level. When WAKEUP signal changes to LOW, the gate output level becomes to LOW too. In this state HIGH level on UART TX is unable to change the output level of the AND gate.

The AND gate has Smitt trigger inputs with VT+ in the range of 0.75-1.16V and VT- in the range of 0.5-0.85V.

Wavewform

Channel | Signal
--- | ---
**CH1:** | Buffer in (TP4)
**CH2:** | WAKEUP (U2.1)
**CH3:** | AND gate B input (U2.2)
**CH4:** | OE (U2.4)

#### Output disable

Wavewform

Channel | Signal
--- | ---
**CH1:** | Buffer in (TP4)
**CH2:** | WAKEUP (U2.1)
**CH3:** | AND gate B input (U2.2)
**CH4:** | OE (U2.4)

#### Level shifting

U3 converts 1.8V logic levels from the GPS to 3.3V required by the camera.

Wavewform

Channel | Signal
--- | ---
**CH1:** | Buffer in (TP4)
**CH2:** | WAKEUP (U2.1)
**CH4:** | Out (J1.3)

#### Results and conclusions

Output enable and level shifting circuits work as expected.

## Tests with the GPS module assembled

#### Wake-up with GPS assembled

Wavewform

Channel | Signal |
--- | ---
**CH1:** | 3.3V (TP2)
**CH2:** | WAKEUP (U2.1)
**CH3:** | UART TX (TP4)
**CH4:** | Out (J1.3)

#### Power-off with GPS assembled

Wavewform

Channel | Signal |
--- | ---
**CH1:** | 3.3V (TP2)
**CH2:** | WAKEUP (U2.1)
**CH3:** | UART TX (TP4)
**CH4:** | Out (J1.3)

#### GPS on

Wavewform

Channel | Signal |
--- | ---
**CH2:** | Push button (SW1.1)
**CH3:** | GPS ON_OFF (U5.4)
**CH4:** | WAKEUP (U2.1)

**Ripple of the 3.3V supply when GPS turns on**

Wavewform

Wavewform

Channel | Signal |
--- | ---
**CH1:** | 3.3V (TP2)
**CH4:** | WAKEUP (U2.1)

#### GPS off

Wavewform

Channel | Signal |
--- | ---
**CH2:** | Push button (SW1.1)
**CH3:** | GPS ON_OFF (U5.4)
**CH4:** | WAKEUP (U2.1)

**Ripple of the 3.3V supply when GPS turns off**

Wavewform

Wavewform

Channel | Signal |
--- | ---
**CH1:** | 3.3V (TP2)
**CH4:** | WAKEUP (U2.1)

#### GPS wake-up and buffer otuput enable

**GPS on**

Wavewform

Channel | Signal |
--- | ---
**CH1:** | GPS ON_OFF (U5.4)
**CH2:** | UART TX (TP4)
**CH3:** | OE (U2.4)
**CH4:** | Out (J1.3)

**GPS off**

Wavewform

Channel | Signal |
--- | ---
**CH1:** | GPS ON_OFF (U5.4)
**CH2:** | UART TX (TP4)
**CH3:** | OE (U2.4)
**CH4:** | Out (J1.3)

#### Logic levels

Wavewform

Channel | Signal |
--- | ---
**CH1:** | UART TX (TP4)
**CH4:** | Out (J1.3)

#### Power consumption

After wake-up, the GPS module enters the acquisition state and consumes around 60mA. Then, after 6-7 minutes, when tested inside a building, it enters the tracking state and consumes around 30mA. When it is turned off by toggling the ON_OFF pin, it consumes less than 100uA.

The circuit with all the additional components consumes 43-47mA in acquisition mode after wake-up, 23-25mA in the tracking mode and 40uA when the GPS is turned off. In the tracking mode after the position is acquired, current consumption doesn't change much and remains in the range of 20-25mA.

**Input current after power off**

Wavewform

During the first 60 seconds the circuit is in the off mode and the input current is at its minimum of ~40uA. Then, during approx. 6 minutes, the circuit consumes ~40-45mA. Then, it is turned off and consumes ~40uA again.

**Input current after turning the circuit off and on again**

Wavewform

In this test the GPS was put to the standby state by the On/off button and then was put to the active state again. The acquisition state lasts approximately 20 seconds, then the module enters the tracking state and the circuit consumes ~25mA.

## Tests with the camera

The next step was to test the circuit connected to my Nikon D610. The camera supplies voltage of 5-6V depending on the load current.

### Input voltage ripple

The aim of these tests is to measure the ripple voltage on the input voltage which comes from the camera.

#### GPS off

Input ripple when the GPS module is in hibernate state. In this state it consumes ~40uA and switching frequency of the buck converter is very low. The input voltage is 5.909V.

Wavewform

Channel | Signal |
--- | ---
**CH1:** | 5V (TP1)

#### GPS in acquisition mode

In this mode the circuit draws ~47mA from the source. Voltage supplied by the camera is 5.695V.

Wavewform

Channel | Signal |
--- | ---
**CH1:** | 5V (TP1)

#### GPS in tracking mode

In this mode the circuit draws ~25mA from the source. Voltage supplied by the camera is 5.720V.

Wavewform

Channel | Signal |
--- | ---
**CH1:** | 5V (TP1)

#### Reducing input ripples

These ripple voltages look high. They depend on the value of C5 whose value was 4.7uF in the previous tests. The following waveforms were obtained after increasing the value of C5 to 22uF.

**GPS off**

Wavewform

**Acquisition mode**

Wavewform

**Tracking mode**

Wavewform

Channel | Signal |
--- | ---
**CH1:** | 5V (TP1)

Increasing C5 to 22uF reduced the ripples by approximately 50%.

#### Ripple on the GPS module

Ripple voltages on the GPS module (U1 pin 4) were too high: 43.2mVpp, 56mvpp and 49.6mVpp in hibernate, acquisition and tracking modes accordingly. The high ripples on 3.3V were caused by high input ripples of the camera power supply. I had to increase the value of C1 to 22uF in order to reduce the ripple voltage.

**GPS off**

Wavewform

The ripple is ~13mVpp not including the small spikes.

**Acquisition mode**

Wavewform

**Tracking mode**

In the tracking mode the current of the GPS module changes many times per second. It can be seen on the amplitude and frequency of the ripple voltage. During the time of high current consumption the ripple falls to ~15mVpp and when the GPS current is low, the ripple can reach ~50mVpp. The GPS module has an internal LDO which should be able to deal with such ripple.

Wavewform

Wavewform

Wavewform

Channel | Signal |
--- | ---
**CH1:** | 3.3V (TP2)

**Tracking mode after acquiring position**

Wavewform

Channel | Signal |
--- | ---
**CH1:** | 3.3V (TP2)

### GPS on and off

When nothing is connected to the camera, the voltage on the UART pin of the GPS connector is 2.7V. In order to prevent possible overload, I changed R6 from 33 Ohm to 300 Ohm.

When the GPS is turned off, the output of U3 enters Hi-Z state and the voltage on its output is set by the camera. It explains why when the GPS is off, the voltage on U3 output is 2.7V.

#### GPS on

Wavewform

Channel | Signal |
--- | ---
**CH1:** | GPS ON_OFF (U5.4)
**CH3:** | UART TX (TP4)
**CH4:** | Out (J1.3)

#### GPS off

Wavewform

Channel | Signal |
--- | ---
**CH1:** | GPS ON_OFF (U5.4)
**CH3:** | UART TX (TP4)
**CH4:** | Out (J1.3)

#### Logic levels

Wavewform

Channel | Signal |
--- | ---
**CH3:** | UART TX (TP4)
**CH4:** | Out (J1.3)

## Changes to the circuit during the tests

1. C1 and C5 changed to 22uF.
2. R9 changed to 10kOhm.
3. R6 changed to 300Ohm.

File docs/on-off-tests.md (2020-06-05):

# ORG1411 GPS Module On/Off Tests

# Autonomous Power-On

Connecting WAKEUP output (pin 6) to ON_OFF input (pin 1) enables automatic GPS module start from Ready-To-Start state to Full Power state.

Schematic

In the first version of Nikon GPS WAKEUP output (pin 6) is connected to ON_OFF input (pin 1) through the 30 Ohm resistor R2.

Scope Image

Channel  | Signal
--- | ---
**CH1:** | 3.3V
**CH2:** | None
**CH3:** | WAKEUP (pin 6)
**CH4:** | GPS_TX (p)in 3)

# On/Off Switch Configuration

In this configuration the GPS module is turned on and off by ON_OFF signal (pin 1) which is controlled by an external on/off button.

## Wake-Up After Power-On

GPS module wake-up with ON_OFF and WAKEUP disconnected.

Scope Image

Channel  | Signal
--- | ---
**CH1:** | 3.3V
**CH2:** | WAKEUP (pin 6)
**CH3:** | ON_OFF (pin 1)
**CH4:** | GPS_TX (pin 3)

Time from 3.3V wake-up to WAKEUP rise is 207.404ms. WAKEUP pulse length is 366us.

## On/Off Sequence

The ON_OFF pulse was generated by an external AWG.

Scope Image

Scope Image

Channel  | Signal
--- | ---
**CH1:** | 3.3V
**CH2:** | WAKEUP (pin 6)
**CH3:** | ON_OFF (pin 1)
**CH4:** | GPS_TX (pin 3)

## GPS On Sequence

Scope Image

Channel  | Signal
--- | ---
**CH1:** | 3.3V
**CH2:** | WAKEUP (pin 6)
**CH3:** | ON_OFF (pin 1)
**CH4:** | GPS_TX (pin 3)

## GPS Off Sequence

Scope Image

Channel  | Signal
--- | ---
**CH1:** | 3.3V
**CH2:** | WAKEUP (pin 6)
**CH3:** | ON_OFF (pin 1)
**CH4:** | GPS_TX (pin 3)

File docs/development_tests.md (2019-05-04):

# Development tests of DIY GPS for Nikon DSLR

## Test equipment

1. Siglent SDS1204X-E oscilloscope
2. GOPHET CPS-3205 II power supply
3. UNI-T UT61E DMM
4. Siglent SDG1032X signal generator

## Tested Circuit
DUT

## Tests without the GPS module
The GPS module is hard to manually solder and especially desolder. Thus, before assembling it, I wanted to make sure that the circuit works as expected.

### Power-on

Power-on without GPS

Channel  | Signal
--- | ---
**CH1:** | 5V
**CH2:** | 3.3V_EN (U4.3)
**CH3:** | 3.3V
**CH4:** | GPS_OUT

### Power-off

Power-on without GPS

Channel  | Signal
--- | ---
**CH1:** | 5V
**CH2:** | 3.3V_EN (U4.3)
**CH3:** | 3.3V
**CH4:** | GPS_OUT

### On/off button

**Turning 3.3V on**

Power-on without GPS

Channel  | Signal
--- | ---
**CH2:** | ON_SW (U3.1)
**CH3:** | 3.3V_EN (U4.3)
**CH4:** | 3.3V

**Turning 3.3V off**

Power-on without GPS

Channel  | Signal
--- | ---
**CH2:** | ON_SW (U3.1)
**CH3:** | 3.3V_EN (U4.3)
**CH4:** | 3.3V

### Logic level shifting

Logic level shifting was tested by injecting pulses to the input of U2. Pulse frequency was 2400Hz and amplitude 3.3V.

**Rise time**

Power-on without GPS

**Fall time**

Power-on without GPS

**Output pulses with 3.3V input**

Power-on without GPS

**Logic level shifting with 2.475V input**

According to ORG1411 datasheet, it has the following logic levels:

Parameter | Symbol | Min | Max | Unit
---|---|---|---|---
Output Voltage Low State | V<sub>OL</sub> | | 0.4 | V
Output Voltage High State | V<sub>OH</sub> | 0.75*Vcc | | V

Vcc in this circuit is 3.3V, therefore, V<sub>HIGH</sub> is 2.475V.

Later, tests with GPS module demonstrated that these pulses don't reflect the real-world voltage levels.

Power-on without GPS

Channel  | Signal
--- | ---
**CH1:** | GPS_TX (C2)
**CH4:** | GPS_OUT

## Tests with the GPS module

The same tests were performed with the GPS module assembled.

### Power-on

Power-on without GPS

Channel  | Signal
--- | ---
**CH1:** | 5V
**CH2:** | 3.3V_EN (U4.3)
**CH3:** | 3.3V
**CH4:** | GPS_OUT

### Power-off

The pulses on the GPS_OUT line are UART transmissions of the GPS module.

Power-on without GPS

Power-on without GPS

Channel  | Signal
--- | ---
**CH1:** | 5V
**CH2:** | 3.3V_EN (U4.3)
**CH3:** | 3.3V
**CH4:** | GPS_OUT

### On/off button

**Turning 3.3V on**

Power-on without GPS

Channel  | Signal
--- | ---
**CH2:** | ON_SW (U3.1)
**CH3:** | 3.3V_EN (U4.3)
**CH4:** | 3.3V

**Turning 3.3V off**

Power-on without GPS

Channel  | Signal
--- | ---
**CH2:** | ON_SW (U3.1)
**CH3:** | 3.3V_EN (U4.3)
**CH4:** | 3.3V

### Logic level shifting

**Rise time**

Power-on without GPS

**Fall time**

Power-on without GPS

**Output pulses with 3.3V input**

Power-on without GPS

Channel  | Signal
--- | ---
**CH1:** | GPS_TX (C2)
**CH4:** | GPS_OUT

This test shows that the real logic levels of the ORG1410-PM04 UART is 1.8V. According to the SN74LV1T126DBVR datasheet, it is not supposed to work with 1.8V input when powered with 5.0V. This test shows that it works well, however, its performance can't be guaranteed.

### UART waveforms

Power-on without GPS

Power-on without GPS

Channel  | Signal
--- | ---
**CH1:** | GPS_TX (C2)
**CH4:** | GPS_OUT

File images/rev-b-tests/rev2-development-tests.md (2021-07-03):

# Design validation DIY GPS for Nikon DSLR Revision B

## Test equipment

1. Siglent SDS1204X-E oscilloscope
2. GOPHET CPS-3205 II power supply
3. UNI-T UT61E DMM
4. Siglent SDG1032X signal generator

## Tested Circuit
Schematic

## Tests without the GPS module
The GPS module is hard to manually solder and especially desolder. Therefore, before assembling it, I wanted to make sure that all the circuits works as expected.

### Power supply

Tests with no load were done with all the parts assembled except GPS module.

#### Wake-up with no load

Wavewform

Channel | Signal |
--- | ---
**CH1:** | 5V input (TP1)
**CH4:** | 3.3V (TP2)

#### Power-off with no load

Wavewform

Channel | Signal |
--- | ---
**CH1:** | 5V input (TP1)
**CH4:** | 3.3V (TP2)

#### Wake-up with load

Wake-up with load was tested with a 33 Ohm resistor (100mA load current) connected between the buck output and GND.

Wavewform

Channel | Signal |
--- | ---
**CH1:** | 5V input (TP1)
**CH4:** | 3.3V (TP2)

#### Power-off with load

Wavewform

Channel | Signal |
--- | ---
**CH1:** | 5V input (TP1)
**CH4:** | 3.3V (TP2)

#### Zoom-in on the wake-up with load

Wavewform

Channel | Signal |
--- | ---
**CH4:** | 3.3V (TP2)

Vout start-up as shown in the datasheet:

Wavewform

#### Ripple without load

According to the datasheet, at light load currents, the device operates in power save mode and the output voltage ripple is independent of the output capacitor value. The output voltage ripple is set by the internal comparator thresholds. The typical output voltage ripple is 1% of the output voltage Vo, therefore we'd expect ripple of 33mVpp.

Wavewform

Channel | Signal |
--- | ---
**CH1:** | 3.3V (TP2)

#### Ripple with 100mA load

Wavewform

Channel | Signal |
--- | ---
**CH1:** | 3.3V (TP2)

The converter shows acceptable ripple at 100mA load.

#### Ripple with 15mA load

Wavewform

Channel | Signal |
--- | ---
**CH1:** | 3.3V (TP2)

#### Ripple with 40mA load

40mA current was chosen as a typical load current of the GPS module.

Wavewform

Channel | Signal |
--- | ---
**CH1:** | 3.3V (TP2)

### Line regulation

The DC-DC converter was tested with a load of 70 Ohm consisting of a 68 Ohm resistor and 2 Ohm internal resistance of the ammeter.

Test conditions | Vin, V | Iin, mA | Vout, V | Iout, mA | Efficiency, %
--- | --- | --- | --- | --- | ---
Vin = 4.5V, RL=70 Ohm | 4.498 | 36.59 | 3.3431 | 46.60 | 94.65%
Vin = 5.0V, RL=70 Ohm | 5.004 | 34.23 | 3.3434 | 47.90 | 93.49%
Vin = 5.5V, RL=70 Ohm | 5.503 | 31.66 | 3.3426 | 48.40 | 92.86%

### Load regulation

Load regulation was tested with three load currents: 5mA, 50mA and 100mA. It was difficult to get precise currents because fixed resistors were used as loads.

Test conditions | Vin, V | Iin, mA | Vout, V | Iout, mA | Efficiency, %
--- | --- | --- | --- | --- | ---
Vin = 5.0V, RL=682 Ohm | 5.0099 | 3.59 | 3.3407 | 5.00 | 92.77%
Vin = 5.0V, RL=70 Ohm | 5.0039 | 34.58 | 3.3434 | 48.50 | 93.71%
Vin = 5.0V, RL=35 Ohm | 5.0043 | 67.09 | 3.3107 | 94.50 | 93.19%

### Dynamic Load

Dynamic load was tested with a fixed resistors, switched by a MOSFET. Switching frequency was 1kHz with duty cycle of 50%. A sense resistor of 1 Ohm was used to monitor the load current.

Dynamic load schematic

**Switching between 4.4mA and 52mA (743 Ohm and 62 Ohm)**

Wavewform

Wavewform

Wavewform

Channel | Signal |
--- | ---
**CH1:** | 3.3V (TP2)
**CH4:** | Current sense

The waveforms show ripple frequency and amplitude change when the load current changes.

**Switching between 4.6mA and 87mA (714 Ohm and 33 Ohm)**

Wavewform

Wavewform

Wavewform

Channel | Signal |
--- | ---
**CH1:** | 3.3V (TP2)
**CH4:** | Current sense

There are spikes of approx. 200mV when the load current changes from 4.6mA to almost 100mA. Similar spikes can are shown in the datasheet of TPS62203.

Wavewform

#### Results and conclusions

At first the output capacitor was a Samsung CL10A106KP8NNNC 10uF 0603 capacitor. The ripple at light load was 37mVpp and the ripple at 100mA load was 76mVpp. After changing the capacitor to Samsung CL21A226MPCLRNC 22uF 10V 0805 the ripple became 27.2mVpp and 18mVpp which is acceptable for this design.

Ripple at low currents (15-40mA) reaches 50mV which is relatively high but the GPS module has a built-in LDO which is supposed to be able to deal with it.

According to the datasheet of the ORG1411 GPS, it can have inrush current of up to 100mA for about 20μs. Maximum steady-state current is 47mA during acquisition. The power supply used in this project will be able to supply these currents to the GPS module.

### On/off button

#### Wake-up

Wavewform

Channel | Signal
--- | ---
**CH1:** | 3.3V (TP2)
**CH2:** | Push button (SW1.1)
**CH3:** | Schmitt trigger in (U5.2)
**CH4:** | Schmitt trigger out (U5.4)

Pulse duration on the output of the Schmitt trigger is 36.4ms. Start time of the GPS module is at least 300ms. During the start period of the GPS module the state of the ON_OFF pin is ignored.

#### On/off pulse

Wavewform

Channel | Signal
--- | ---
**CH2:** | Push button (SW1.1)
**CH3:** | Schmitt trigger in (U5.2)
**CH4:** | Schmitt trigger out (U5.4)

On/off pulse duration is around 254ms and depends on the time the button remains pressed. ORG1411 datasheet recommends ON_OFF pulse duration of 100ms.

#### Push button debouncing

Wavewform

Channel | Signal
--- | ---
**CH2:** | Push button (SW1.1)
**CH3:** | Schmitt trigger in (U5.2)
**CH4:** | Schmitt trigger out (U5.4)

The debouncing time of the circuit is approx. 14.8ms. Increasing R8 will increase this time.

#### Results and conclusions

Push button debouncing circuit works as expected.

### Logic level shifter and output enable

#### Wake-up

Wavewform

Channel | Signal
--- | ---
**CH1:** | 3.3V (TP2)
**CH2:** | Buffer in (TP4)
**CH3:** | OE (U3.1)
**CH4:** | Out (J1.3)

#### Power-off

Wavewform

Channel | Signal
--- | ---
**CH1:** | 3.3V (TP2)
**CH2:** | Buffer in (TP4)
**CH3:** | OE (U3.1)
**CH4:** | Out (J1.3)

#### Output enable

Output enable circuit works as a latch. After WAKEUP becomes HIGH, the latch is triggered by the first UART TX LOW-HIGH transition and the AND gate output becomes HIGH. In this state, resistor R5 pulls the B input of the AND gate up independently of the UART TX level. When WAKEUP changes to LOW, the gate output level becomes to LOW too. In this state HIGH level on UART TX is unable to change the output level of the AND gate.

Wavewform

Channel | Signal
--- | ---
**CH1:** | Buffer in (TP4)
**CH2:** | WAKEUP (U2.1)
**CH3:** | AND gate B input (U2.2)
**CH4:** | OE (U2.4)

#### Output disable

Wavewform

Channel | Signal
--- | ---
**CH1:** | Buffer in (TP4)
**CH2:** | WAKEUP (U2.1)
**CH3:** | AND gate B input (U2.2)
**CH4:** | OE (U2.4)

#### Level shifting

Wavewform

Channel | Signal
--- | ---
**CH1:** | Buffer in (TP4)
**CH2:** | WAKEUP (U2.1)
**CH4:** | Out (J1.3)

#### Results and conclusions

Output enable and level shifting circuits work as expected.

## Tests with the GPS module assembled

#### Wake-up with GPS assembled

Wavewform

Wavewform

Channel | Signal |
--- | ---
**CH1:** | 3.3V (TP2)
**CH2:** | WAKEUP (U2.1)
**CH3:** | UART TX (TP4)
**CH4:** | Out (J1.3)

#### Power-off with GPS assembled

Wavewform

Channel | Signal |
--- | ---
**CH1:** | 3.3V (TP2)
**CH2:** | WAKEUP (U2.1)
**CH3:** | UART TX (TP4)
**CH4:** | Out (J1.3)

#### GPS on

Wavewform

Channel | Signal |
--- | ---
**CH2:** | Push button (SW1.1)
**CH3:** | GPS ON_OFF (U5.4)
**CH4:** | WAKEUP (U2.1)

**Ripple of the 3.3V supply when GPS turns on**

Wavewform

Wavewform

Channel | Signal |
--- | ---
**CH1:** | 3.3V (TP2)
**CH4:** | WAKEUP (U2.1)

#### GPS off

Wavewform

Channel | Signal |
--- | ---
**CH2:** | Push button (SW1.1)
**CH3:** | GPS ON_OFF (U5.4)
**CH4:** | WAKEUP (U2.1)

**Ripple of the 3.3V supply when GPS turns off**

Wavewform

Wavewform

Channel | Signal |
--- | ---
**CH1:** | 3.3V (TP2)
**CH4:** | WAKEUP (U2.1)

#### GPS wake-up and buffer otuput enable

**GPS on**

Wavewform

Channel | Signal |
--- | ---
**CH1:** | GPS ON_OFF (U5.4)
**CH2:** | UART TX (TP4)
**CH3:** | OE (U2.4)
**CH4:** | Out (J1.3)

**GPS off**

Wavewform

Channel | Signal |
--- | ---
**CH1:** | GPS ON_OFF (U5.4)
**CH2:** | UART TX (TP4)
**CH3:** | OE (U2.4)
**CH4:** | Out (J1.3)

#### Logic levels

Wavewform

Channel | Signal |
--- | ---
**CH1:** | UART TX (TP4)
**CH4:** | Out (J1.3)

#### Power consumption

After wake-up, the GPS module enters the acquisition state and consumes around 60mA. Then, after 6-7 minutes, when tested inside a building, it enters the tracking state and consumes around 30mA. When it is turned of by toggling the ON_OFF pin, it consumes less than 100uA.

The circuit with all the additional components consumes 43-47mA in acquisition mode after wake-up, 23-25mA in the tracking mode and 40uA when the GPS is turned off. In the tracking mode after the position is acquired, current consumption doesn't change much and remains in the range of 20-25mA.

**Input current after wake-up**

Wavewform

Here we see that during the first 60 seconds the circuit is in the off mode and the input current is at its minimum of ~40uA. Then, during approx. 6 minutes, the circuit consumes ~40-45mA. Then, it is turned off and consumes ~40uA again.

**Input current after turning the circuit off and on again**

Wavewform

Here we see the circuit start-up after it was turned on, turned off and turned on again. The acquisition state lasts approximately 20 seconds. Almost immediately after the power-on, the module enters the tracking state and the circuit consumes ~25mA.

## Tests with the camera

The next step was to test the circuit connected to my Nikon D610. The camera supplies voltage of 5-6V depending on the load current.

### Input voltage ripple

The aim of these tests is to measure the ripple voltage on the input voltage which comes from the camera.

#### GPS off

Input ripple when the GPS module is in hibernate state. In this state it consumes ~40uA and switching frequency of the buck converter is very low. Measured input voltage is 5.909V.

Wavewform

Channel | Signal |
--- | ---
**CH1:** | 5V (TP1)

#### GPS in acquisition mode

In this mode the circuit draws ~47mA from the source. Measured input voltage is 5.695V.

Wavewform

Channel | Signal |
--- | ---
**CH1:** | 5V (TP1)

#### GPS in tracing mode

In this mode the circuit draws ~25mA from the source. Measured input voltage is 5.720V.

Wavewform

Channel | Signal |
--- | ---
**CH1:** | 5V (TP1)

#### Reducing input ripples

These ripple voltages look high. They depend on the value of C5 which is currently 4.7uF. Its footprint is 0805 and the highest 0805 capacitor I have is 22uF (Samsung CL21A226MPCLRNC). The following screenshots show the input ripples after increasing C5.

**GPS off**

Wavewform

**Acquisition mode**

Wavewform

**Tracking mode**

Wavewform

Channel | Signal |
--- | ---
**CH1:** | 5V (TP1)

Increasing C5 lowered the ripples by approximately 50%.

#### Ripple on the GPS module

Ripple voltages on the GPS module (U1 pin 4) were too high: 43.2mVpp, 56mvpp and 49.6mVpp in hibernate, acquisition and tracking mode accordingly. I had to increase the value of C1 to 22uF in order to reduce the ripple voltage.

**GPS off**

Wavewform

The ripple is ~13mVpp not including the small spikes.

**Acquisition mode**

Wavewform

**Tracking mode**

In the tracking mode the current of the GPS module changes many times per second. It can be seen on the amplitude and frequency of the ripple voltage. During the time of high current consumption the ripple falls to ~15mVpp and when the GPS current is low, the ripple can reach ~50mVpp. The GPS module has an internal LDO which should be able to deal with such ripple.

Wavewform

Wavewform

Wavewform

Channel | Signal |
--- | ---
**CH1:** | 3.3V (TP2)

**Tracking mode after acquiring position**

Wavewform

Channel | Signal |
--- | ---
**CH1:** | 3.3V (TP2)

### GPS on and off

When nothing is connected to the camera, the voltage on the UART pin of the GPS connector is 2.7V. In order to prevent possible overload, I changed R6 from 33 Ohm to 300 Ohm.

#### GPS on

Wavewform

Channel | Signal |
--- | ---
**CH1:** | GPS ON_OFF (U5.4)
**CH3:** | UART TX (TP4)
**CH4:** | Out (J1.3)

#### GPS off

Wavewform

Channel | Signal |
--- | ---
**CH1:** | GPS ON_OFF (U5.4)
**CH3:** | UART TX (TP4)
**CH4:** | Out (J1.3)

#### Logic levels

Wavewform

Channel | Signal |
--- | ---
**CH3:** | UART TX (TP4)
**CH4:** | Out (J1.3)

## Changes to the circuit during the tests

1. C1 and C5 changed to 22uF.
2. R9 changed to 10kOhm.
3. R6 changed to 300Ohm.

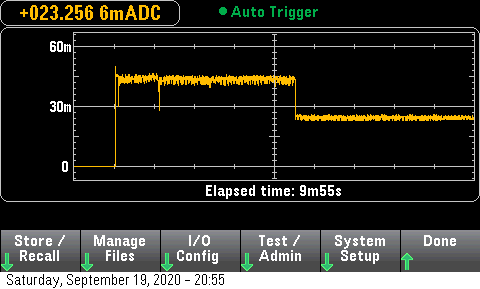
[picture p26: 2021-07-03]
images/rev-b-tests/power-on-1.png

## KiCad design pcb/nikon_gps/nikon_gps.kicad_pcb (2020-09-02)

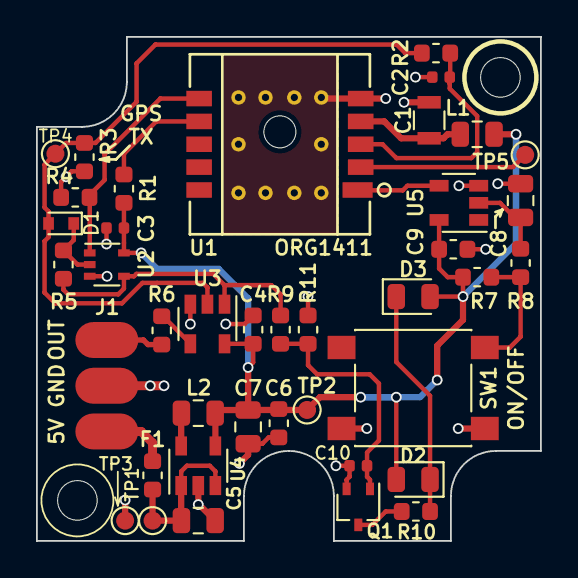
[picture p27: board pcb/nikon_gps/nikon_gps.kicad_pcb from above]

Board: 2 copper layers, 28.0 x 28.0 mm, 42 parts (0 on the bottom side), 21 nets.

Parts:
C1: 100nF; C_0805_NarrowPads
C2: 18pF; C_0402
C3, C10: 100nF; C_0402
C4, C9: 100nF; C_0603
C5: 4.7uF; C_0805
C6: 1nF; C_0603
C7: 10uF; C_0805
C8: 100nF; C_0805
D1: Shottky; D_SOD-523
D2, D3: Green; LED_0805
F1: 0.1A; Fuse_0603
J1: 1x03 pads; Connection_Pads_03
L1: 600Ohm; L_0805
L2: 10uH; L_0805
MH1, MH2: M2 screw; MountingHole_2.2mm_M2_DIN965
Q1: NMOS; SOT-323_SC-70
R1, R3, R4: 10K; R_0603
R2, R6: 33; R_0603
R5: 22K; R_0603
R7, R9: 33K; R_0603
R8: 4.7K; R_0603
R10: 330; R_0603
R11: 100K; R_0603
SW1: ON/OFF; SW_SPST_PTS645_4pin
TP1: 5V; Measurement_Point_Round-SMD-Pad_Small
TP2: 3.3V; Measurement_Point_Round-SMD-Pad_Small
TP3: GND; Measurement_Point_Round-SMD-Pad_Small
TP4: GPS TX; Measurement_Point_Round-SMD-Pad_Small
TP5: 1PPS; Measurement_Point_Round-SMD-Pad_Small
U1: Hornet ORG1411; ORG1411_GPS_ALT
U2: 74AUP1T08; SOT-353_SC-70-5
U3: SN74LV1T126; SOT-23-5
U4: TPS62203DBV; SOT-23-5
U5: 74LVC1G14; SOT-23-5

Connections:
+3V3: C3.2, C4.2, C6.1, C7.1, C9.1, D2.2, D3.2, L1.2, L2.2, R1.1, R7.2, TP2.1, U2.5, U3.5, U4.4, U5.5
+5V: C5.1, F1.1, TP1.1, U4.1, U4.3
/1PPS: TP5.1, U1.2
/3.3V_GPS: C1.2, L1.1, U1.4
/5V_IN: F1.2, J1.1
/BUFFER_IN: D1.2, R2.2, R3.2, TP4.1, U3.2
/BUF_OUT: R6.1, U3.4
/GPS_TX: C2.1, R2.1, U1.3
/OE: R5.2, R9.2, U2.4, U3.1
/ON_OFF: U1.1, U5.4
/ON_SW: R7.1, R8.1, SW1.1
/OUT: J1.3, R6.2
/WAKEUP: R4.1, U1.6, U2.1
/~CTS: R1.2, U1.7
GND: C1.1, C2.2, C3.1, C4.1, C5.2, C6.2, C7.2, C8.2, C9.2, C10.2, J1.2, Q1.2, R3.1, R4.2, R11.1, SW1.3, SW1.4, TP3.1, U1.5, U2.3, U3.3, U4.2, U5.3
unnamed: C8.1, R8.2, U5.2
unnamed: C10.1, Q1.1, R9.1, R11.2
unnamed: D1.1, R5.1, U2.2
unnamed: D2.1, D3.1, R10.2
unnamed: L2.1, U4.5
unnamed: Q1.3, R10.1

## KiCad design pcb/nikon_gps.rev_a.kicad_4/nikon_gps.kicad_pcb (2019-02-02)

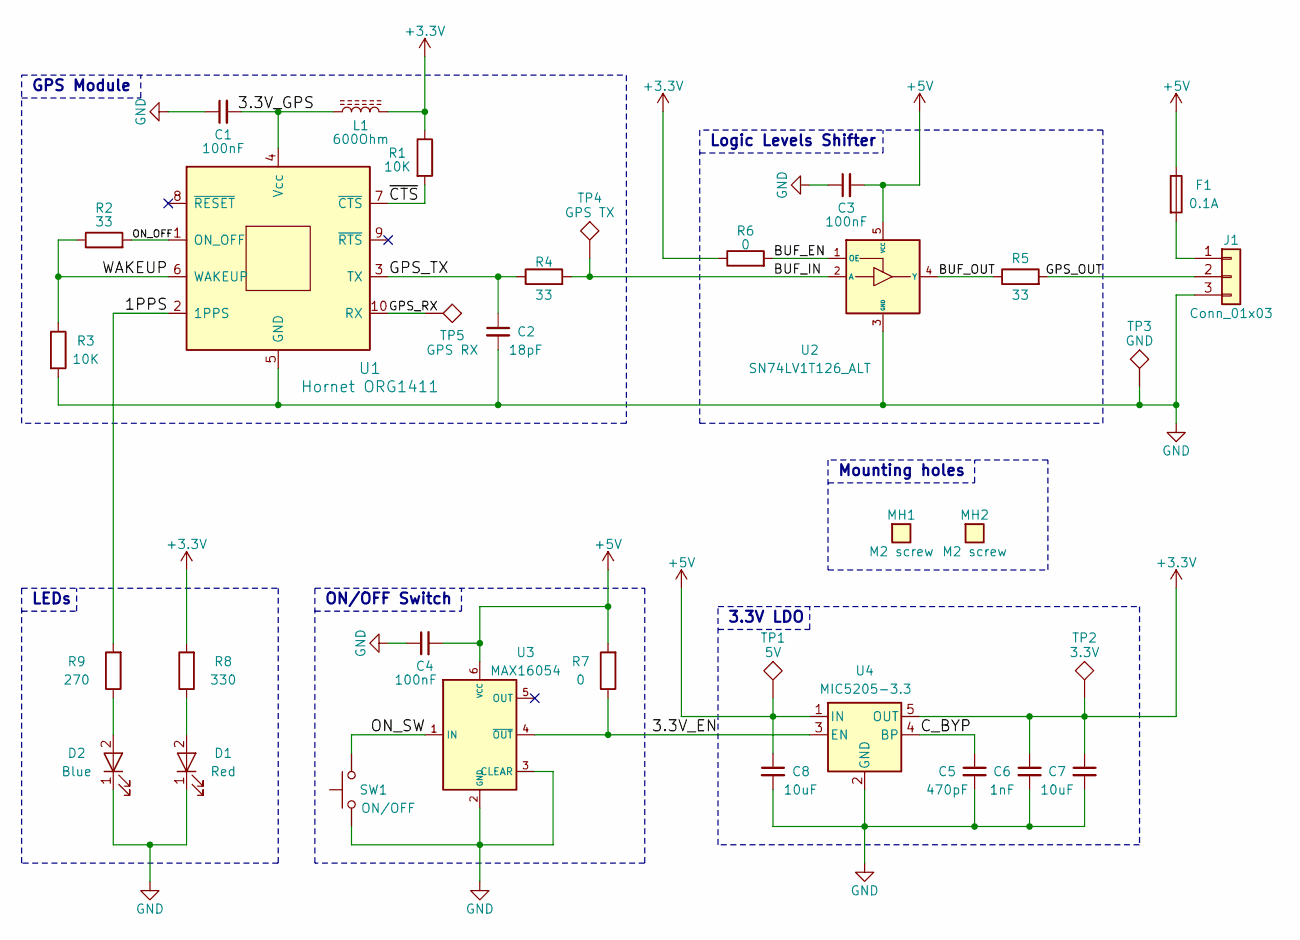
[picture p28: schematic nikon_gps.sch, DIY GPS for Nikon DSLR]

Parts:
C1, C3, C4: 100nF; C_0805
C2: 18pF; C_0603
C5: 470pF; C_0805
C6: 1nF; C_0603
C7, C8: 10uF; C_0805
D1: Red; LED_0805
D2: Blue; LED_0805
F1: 0.1A; R_0603
J1: Conn_01x03; Connection_Pads_03
L1: 600Ohm; L_0805
MH1, MH2: M2 screw; MountingHole_2.2mm_M2_DIN965
R1, R3: 10K; R_0805
R2, R4, R5: 33; R_0805
R6, R7: 0; R_0805
R8: 330; R_0805
R9: 270; R_0805
SW1: ON/OFF; SW_SPST_PTS645
TP1: 5V; Measurement_Point_Round-SMD-Pad_Small
TP2: 3.3V; Measurement_Point_Round-SMD-Pad_Small
TP3: GND; Measurement_Point_Round-SMD-Pad_Small
TP4: GPS TX; Measurement_Point_Square-SMD_1.0mmx1.0mm
TP5: GPS RX; Measurement_Point_Square-SMD_1.0mmx1.0mm
U1: Hornet ORG1411; ORG1411_GPS
U2: SN74LV1T126_ALT; SOT-23-5
U3: MAX16054; SOT-23-6
U4: MIC5205-3.3; SOT-23-5

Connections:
+3V3: C6.1, C7.1, L1.2, R1.1, R6.1, R8.2, TP2.1, U4.5 (OUT)
+5V: C3.2, C4.2, C8.1, F1.1, R7.2, TP1.1, U2.5 (VCC), U3.6 (VCC), U4.1 (IN)
/1PPS: R9.2, U1.2 (1PPS)
/3.3V_EN: R7.1, U3.4 (~OUT), U4.3 (EN)
/3.3V_GPS: C1.2, L1.1, U1.4 (Vcc)
/BUF_EN: R6.2, U2.1 (OE)
/BUF_IN: R4.2, TP4.1, U2.2 (A)
/BUF_OUT: R5.1, U2.4 (Y)
/C_BYP: C5.1, U4.4 (BP)
/GPS_OUT: J1.2, R5.2
/GPS_RX: TP5.1, U1.10 (RX)
/GPS_TX: C2.1, R4.1, U1.3 (TX)
/ON_OFF: R2.2, U1.1 (ON_OFF)
/ON_SW: SW1.2, U3.1 (IN)
/WAKEUP: R2.1, R3.1, U1.6 (WAKEUP)
/~CTS: R1.2, U1.7 (~CTS)
GND: C1.1, C2.2, C3.1, C4.1, C5.2, C6.2, C7.2, C8.2, D1.1 (K), D2.1 (K), J1.3, R3.2, SW1.1, TP3.1, U1.5 (GND), U2.3 (GND), U3.2 (GND), U3.3 (CLEAR), U4.2 (GND)
unnamed: D1.2 (A), R8.1
unnamed: D2.2 (A), R9.1
unnamed: F1.2, J1.1

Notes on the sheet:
3.3V LDO
ON/OFF Switch
Logic Levels Shifter
GPS Module
LEDs
Mounting holes

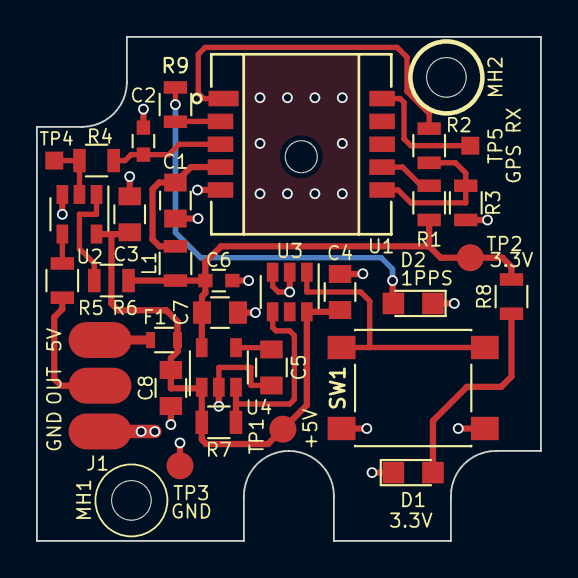
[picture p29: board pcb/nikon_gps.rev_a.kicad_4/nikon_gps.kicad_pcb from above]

Board: 2 copper layers, 28.0 x 28.0 mm, 34 parts (0 on the bottom side), 20 nets.

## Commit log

2019-02-02 KiCAD files and DXF.
    [nikon_gps-B.Cu.gbr, nikon_gps-B.Mask.gbr, nikon_gps-B.SilkS.gbr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]
2019-05-04 Readme and schematics update.
    [nikon_gps.sch]
2019-08-31 Renamed pcb/nikon_gps directory to nikon_gps.kicad4 for creating a backup of the KiCAD 4.x version.
    [nikon_gps-B.Cu.gbr, nikon_gps-B.Mask.gbr, nikon_gps-B.SilkS.gbr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]
2019-08-31 KiCAD 5.1 version of the revision A.
    [nikon_gps-B.Cu.gbr, nikon_gps-B.Mask.gbr, nikon_gps-B.SilkS.gbr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]
2020-04-15 Added photos of the device.
2020-08-01 Final version of revision B.
    [nikon_gps.kicad_pcb, nikon_gps.sch]
2020-09-02 Production files and BOM.
    [nikon-gps-bom-jlcpcb.csv, nikon-gps-bom-pcbway.csv, nikon-gps-bom.ods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]
2021-01-23 1. PCB update. 2. Updated 3D model images.
    [nikon_gps.sch]
2021-07-03 Revision B tests notes.
    [DATA_0.csv, DATA_1.csv, DATA_2.csv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]
